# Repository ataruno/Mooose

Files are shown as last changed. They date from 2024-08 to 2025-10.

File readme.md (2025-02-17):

# Mooose

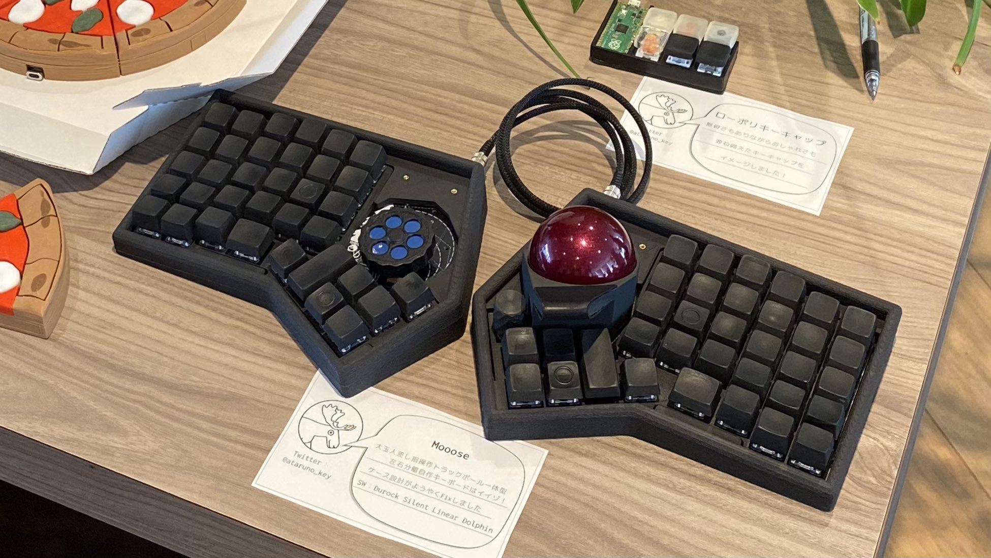
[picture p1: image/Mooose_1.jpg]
Mooose_image


## Features
Keyboard Maintainer: [ataruno](https://github.com/ataruno)  
* Integrated trackball operated with the index finger  
* Supports a 55mm large ball  
* Split design (left and right halves)  
* 70 keys  

## Where to Buy
Booth：[自作キーボード”Mooose”](https://ataruno.booth.pm/items/5795449)

## Build Guide
[ビルドガイドリンク](https://github.com/ataruno/Mooose/blob/main/build_guide/build_guide.md)

ビルドガイドへのQRコード  
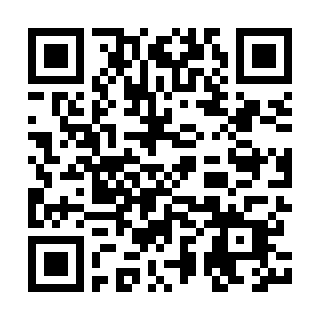
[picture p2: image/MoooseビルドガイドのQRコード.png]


## forCaseDesign
[Moooseのケース設計をしてみたい方へ](https://github.com/ataruno/Mooose/blob/main/forCaseDesign/forCaseDesign.md)  
基板の3Dデータの一部を公開しています。

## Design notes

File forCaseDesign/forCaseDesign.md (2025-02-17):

# Moooseのケース設計をしてみたい方へ
基板の3Dデータの一部を公開します。  

## 3Dデータ(.fbx形式、.stl形式)
[fbx形式 データ置き場リンク](https://github.com/ataruno/Mooose/tree/main/forCaseDesign/forCaseDesign_data/fbx)

[stl形式 データ置き場リンク](https://github.com/ataruno/Mooose/tree/main/forCaseDesign/forCaseDesign_data/stl)

## 簡単な解説
### データのダウンロード
ダウンロードしたいデータファイルまでいき、画像赤枠の"Download raw file"をクリックするとダウンロードできます。  
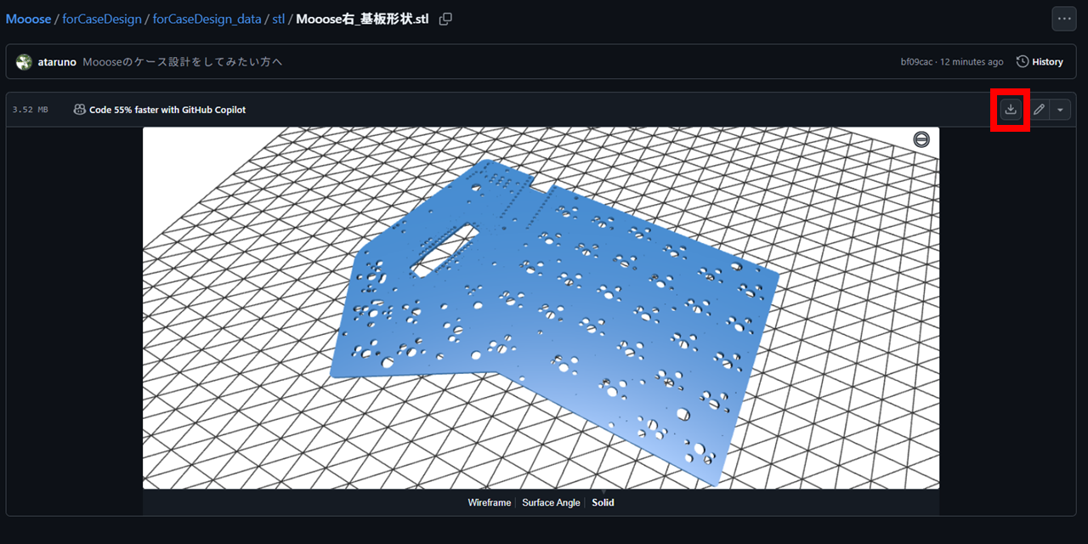
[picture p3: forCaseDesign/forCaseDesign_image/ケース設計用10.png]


### キースイッチの配置
左手側をモチーフに解説します。全体イメージは以下です。  
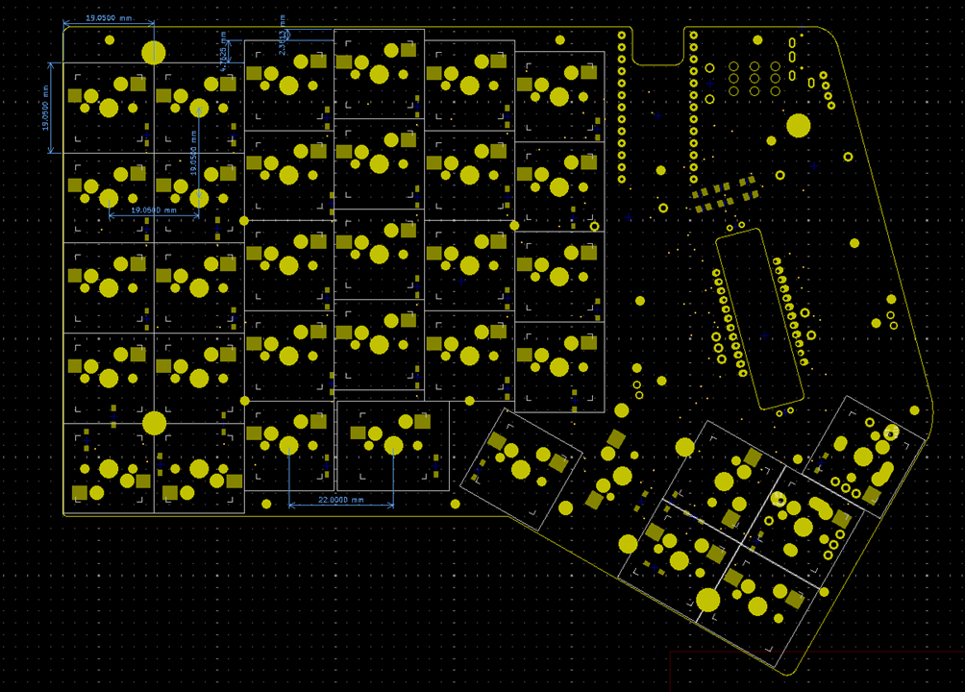
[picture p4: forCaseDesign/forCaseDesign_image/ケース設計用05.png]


キースイッチ一つは19.05mm x 19.05mmで配置しています。  
ずれ量はこの値を基準に1/4ずれ、1/8ずれを使用しています。  
つまり、  
1/4ずれは19.05mm x 1/4 = 4.7625  
1/4ずれは19.05mm x 1/8 = 2.38125  
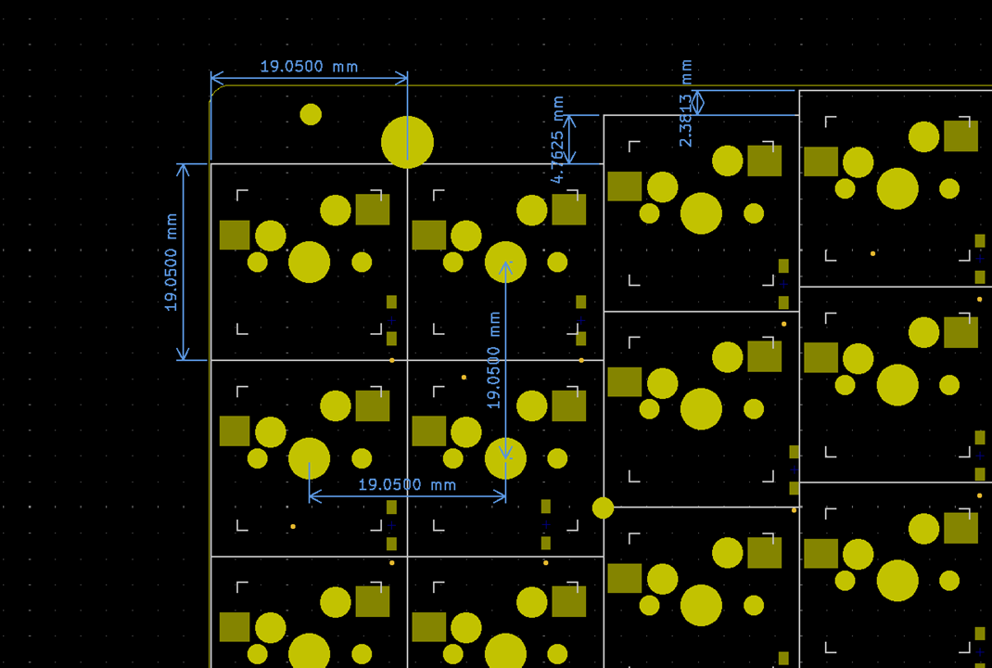
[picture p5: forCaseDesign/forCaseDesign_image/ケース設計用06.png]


真ん中あたりの1.25Uサイズのキースイッチ配置は以下のような感じ。  
隣から22.00mm離れてます。  
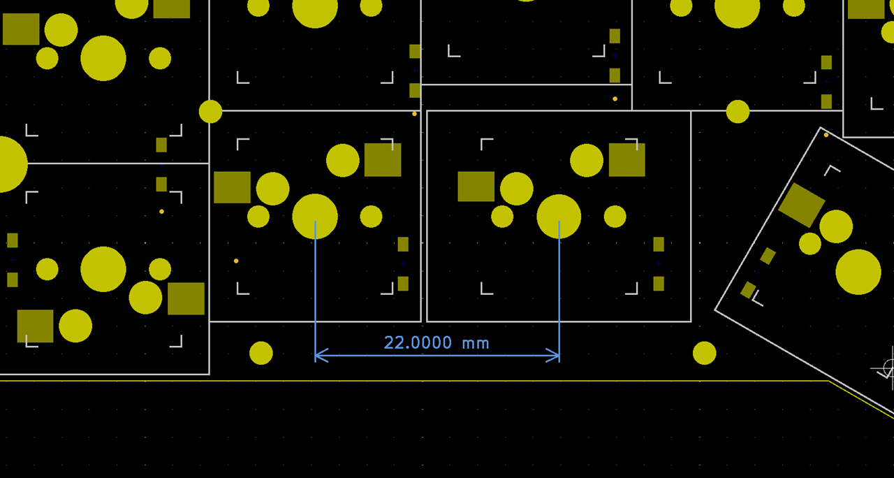
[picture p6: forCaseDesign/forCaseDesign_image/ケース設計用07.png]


### 基板固定用のネジ穴
大きい穴と小さい穴の2種類があります。  
赤丸で囲った穴は直径5.1mm(5mmを通す想定)。黄丸で囲った穴は直径2.1mm(2mmを通す想定)。  
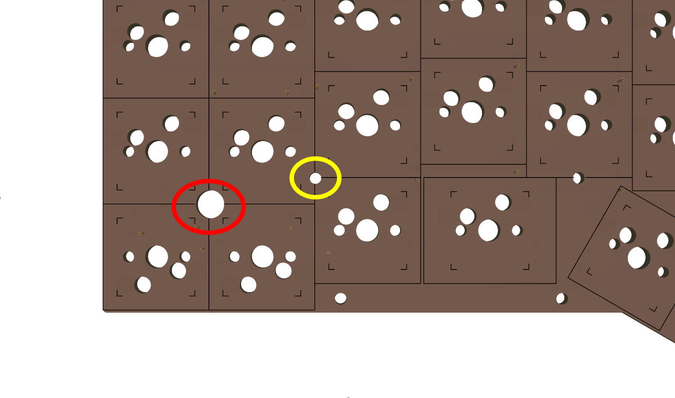
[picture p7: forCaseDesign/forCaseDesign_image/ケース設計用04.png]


### データの取り込み方
使用しているソフトによって異なると思いますが、blenderだと以下です。  
インポートから指定のファイルを選択。  
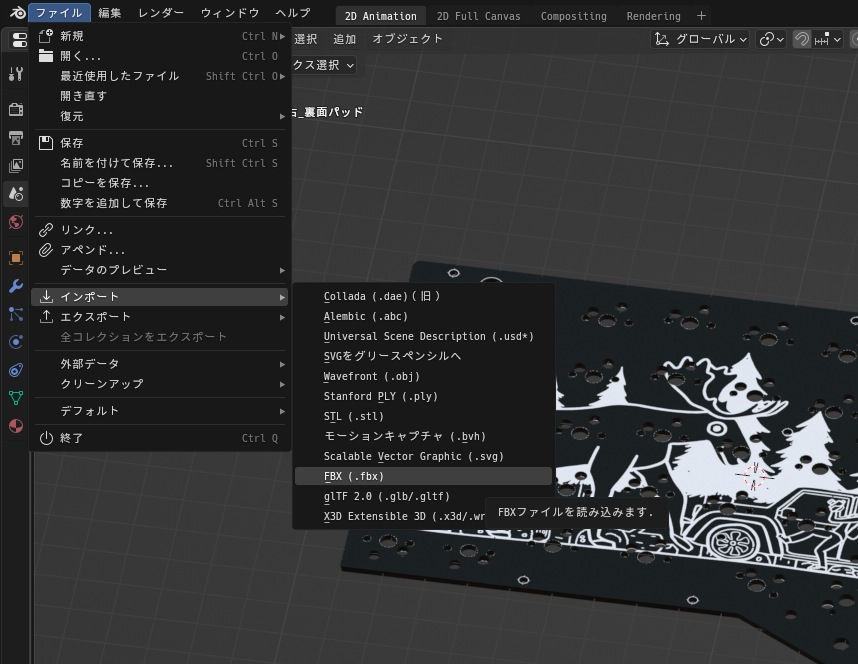
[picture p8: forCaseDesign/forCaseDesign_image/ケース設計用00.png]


fbx形式だとマテリアル(色)がついています。  
また、一つのファイルを読み込むと、4つのデータが取り込まれます。  
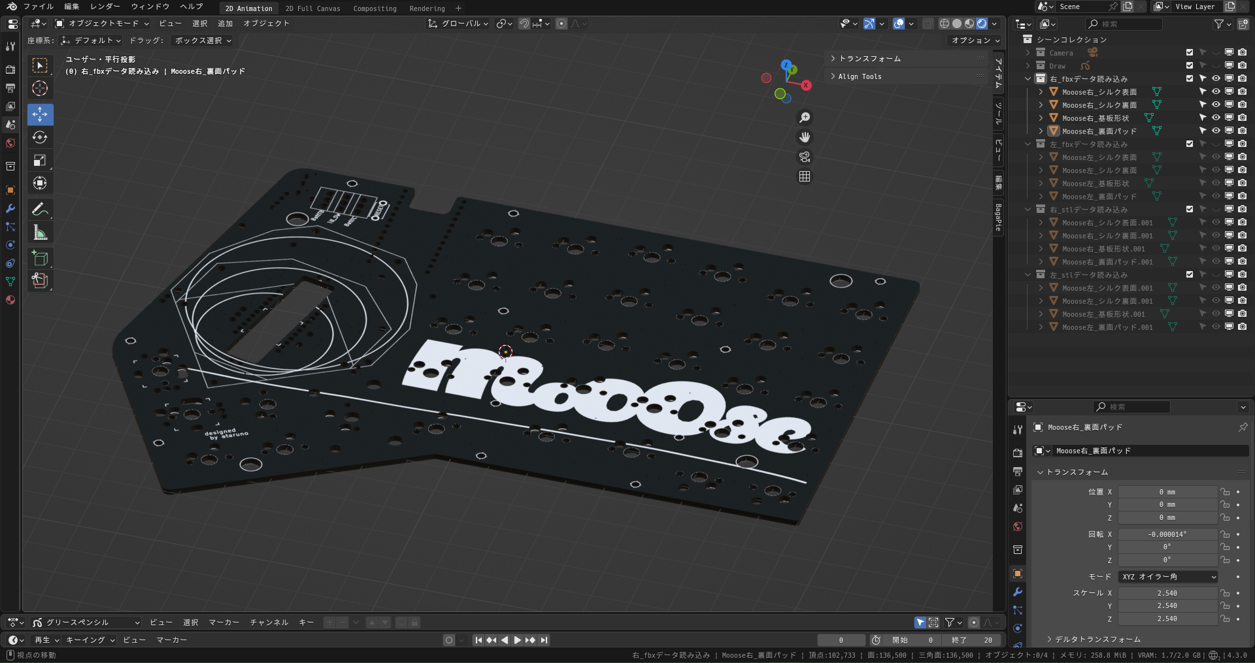
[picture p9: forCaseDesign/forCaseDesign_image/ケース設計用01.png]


stl形式だと色情報がないため真っ白です。  
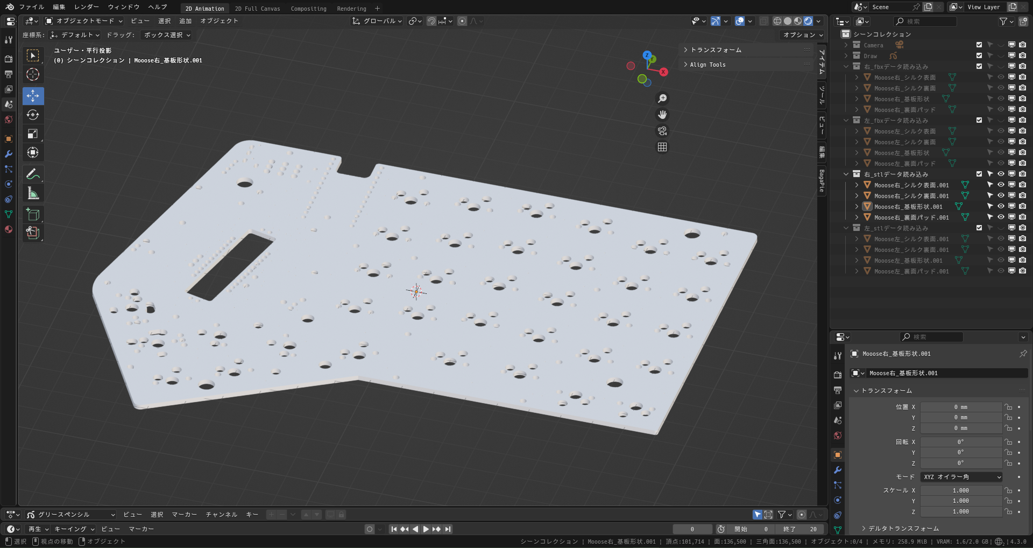
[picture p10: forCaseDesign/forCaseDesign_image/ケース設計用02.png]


ぱっと見見えないけど、位置をずらすと見えたりします。  
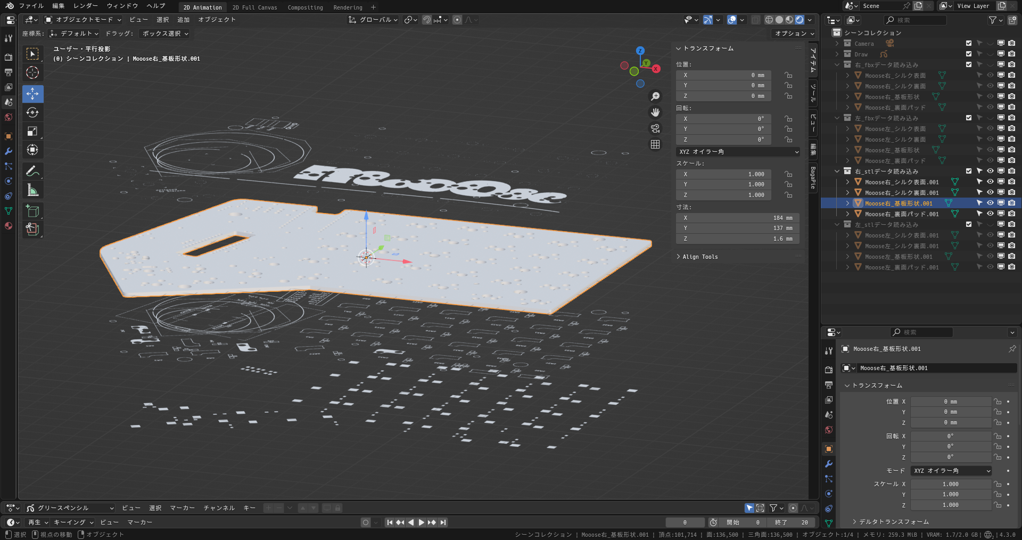
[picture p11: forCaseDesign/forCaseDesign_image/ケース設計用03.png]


## おわりに
ケース設計されたいかたは活用してみてください。
以上です。

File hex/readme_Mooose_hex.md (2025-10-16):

# Moooseのhexファイルごとの解説
2025/08/24現在、トラックボールをつける側とUSB接続する側はそろっている必要があります。  

## mooose_via.hex
* remap対応  
* Master=USB接続:右手  
* トラックボール:右手  

## mooose_via_ML_RightTB.hex
* remap対応  
* Master=USB接続:左手  
* トラックボール:右手  

## mooose_via_Scroll2_MR_RightTB
* remap対応  
* Master=USB接続:右手  
* トラックボール:右手  
* トラボ操作によるスクロール改良版  

## mooose_via_Scroll2_cpi***.hex
* remap対応  
* Master=USB接続:右手  
* トラックボール:右手  
* トラボ操作によるスクロール改良版  
* トラボ感度違いのファイルです。  
  * デフォルトファイルが一番感度が高く、cpiの値が小さくなるほど感度が低くなります。  
  * 不思議なんですが、書き込み終わったら何かキーを打つとcpiが更新されます。

## mooose_via_Scroll2_ML_LeftTB
* remap対応  
* Master=USB接続:左手  
* トラックボール:左手  
* トラボ操作によるスクロール改良版  

## mooose_via_Scroll2_MR_DoubleTB.hex
* remap対応  
* Master=USB接続:右手  
* トラックボール:両方  
  * 右手は通常時マウス操作。レイヤー"LOWER","AHK"状態でスクロール可能。
  * 左手は常時スクロール状態。マウス操作はなし。
* トラボ操作によるスクロール改良版

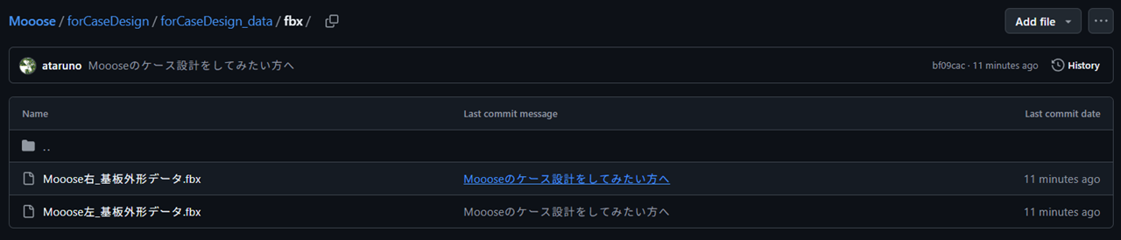
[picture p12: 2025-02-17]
forCaseDesign/forCaseDesign_image/ケース設計用08.png

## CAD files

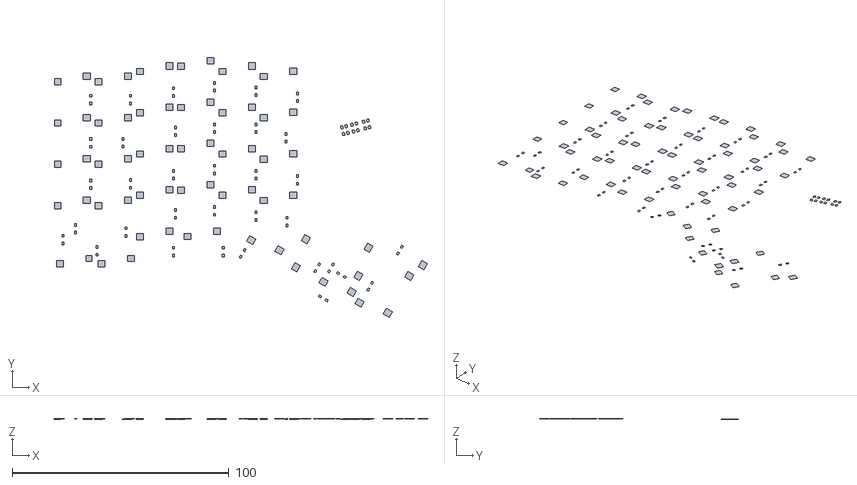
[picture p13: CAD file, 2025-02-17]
forCaseDesign/forCaseDesign_data/stl/Mooose左_裏面パッド.stl
172.0 x 119.8 x 2.86e-05

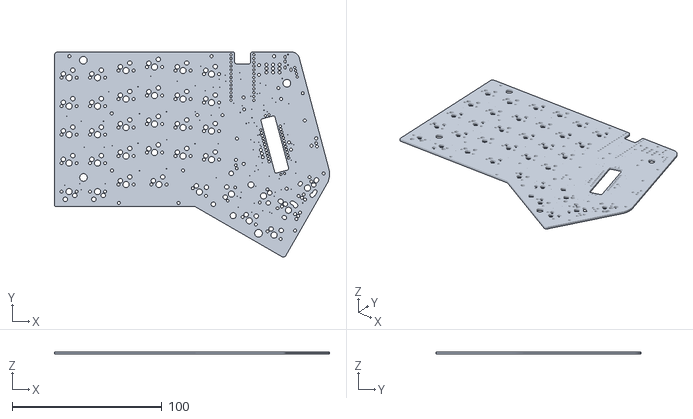
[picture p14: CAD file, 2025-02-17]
forCaseDesign/forCaseDesign_data/stl/Mooose左_基板形状.stl
183.9 x 137.1 x 1.60

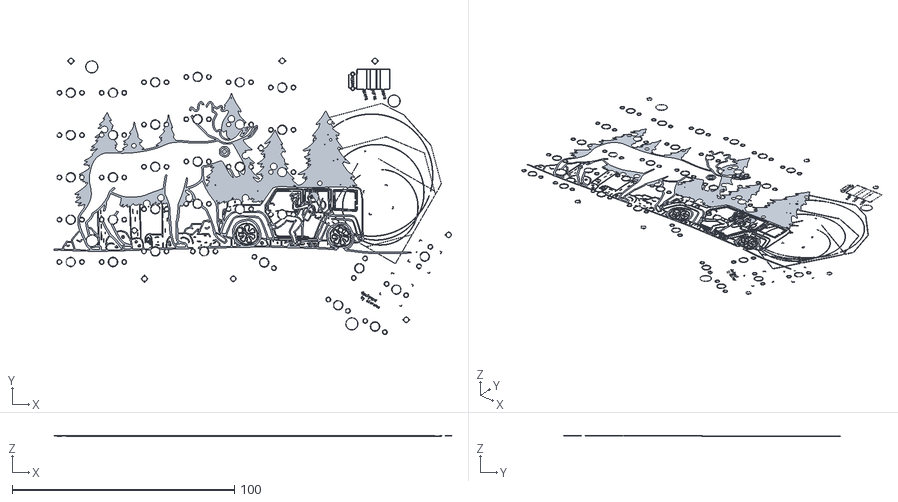
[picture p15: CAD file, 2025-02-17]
forCaseDesign/forCaseDesign_data/stl/Mooose左_シルク表面.stl
179.3 x 124.7 x 2.97e-05

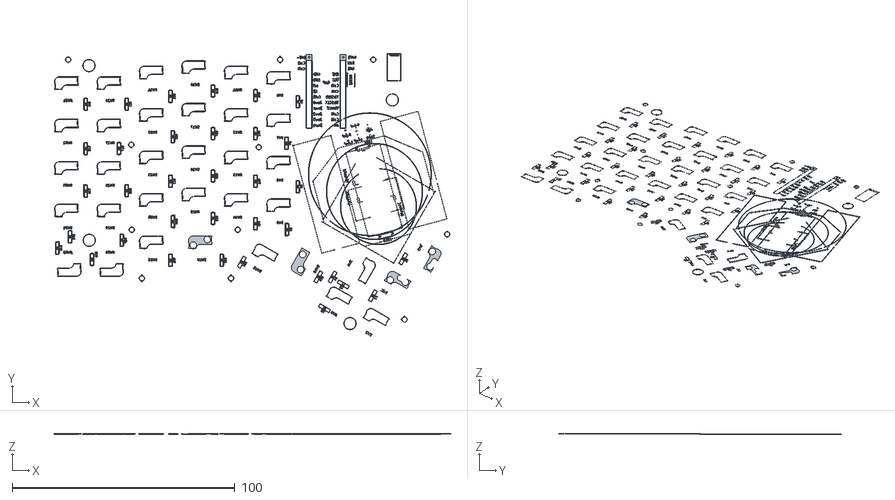
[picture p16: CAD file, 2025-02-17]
forCaseDesign/forCaseDesign_data/stl/Mooose左_シルク裏面.stl
177.7 x 126.9 x 3.03e-05

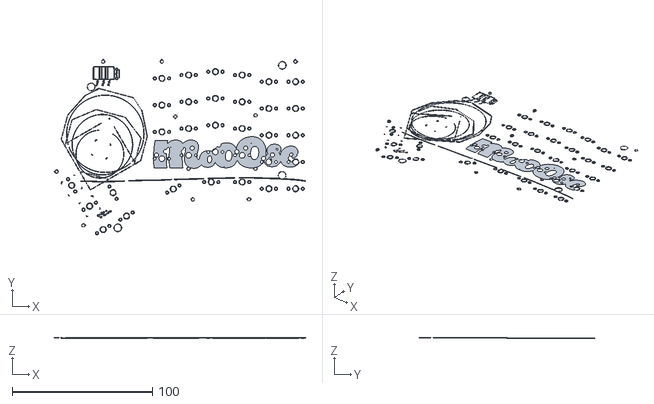
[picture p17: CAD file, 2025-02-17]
forCaseDesign/forCaseDesign_data/stl/Mooose右_シルク表面.stl
178.8 x 124.7 x 2.97e-05

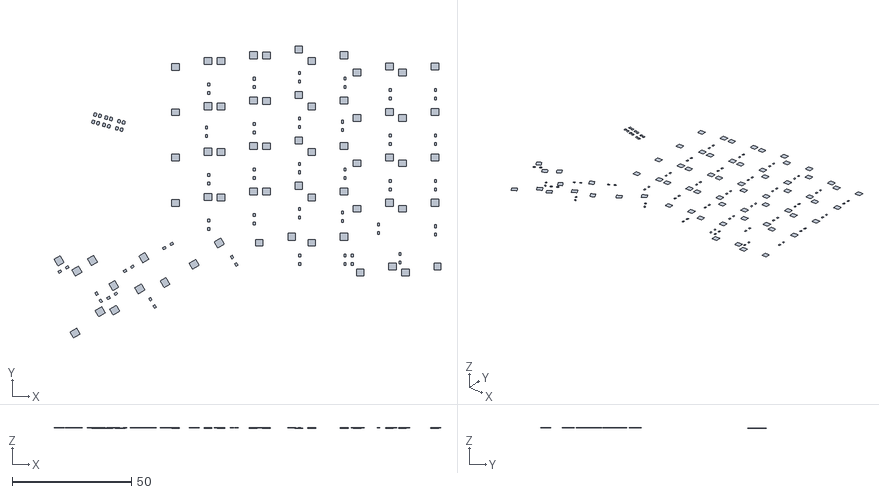
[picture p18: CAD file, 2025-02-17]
forCaseDesign/forCaseDesign_data/stl/Mooose右_裏面パッド.stl
162.4 x 122.5 x 2.93e-05

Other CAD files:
forCaseDesign/forCaseDesign_data/stl/Mooose右_基板形状.stl
forCaseDesign/forCaseDesign_data/stl/Mooose右_シルク裏面.stl

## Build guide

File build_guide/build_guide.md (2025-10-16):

# Moooseのビルドガイド

- [キット内容](#キット内容)
- [ご自身で手配いただくもの](#ご自身で手配いただくもの)
- [はんだ付け](#はんだ付け)
- [組み立て](#組み立て)
- [部品について](#部品について)
- [プログラム書き込み(Remap)](#プログラム書き込みremap)
- [キーマップのカスタマイズ設定](#キーマップのカスタマイズ設定)
- [Userキーについて](#userキーについて)
- [補足:build\_guideの参考情報](#補足build_guideの参考情報)
- [補足:Moooseのケース設計をしてみたい方へ](#補足moooseのケース設計をしてみたい方へ)
- [補足:あれ？動かないな？ってときの確認表](#補足あれ動かないなってときの確認表)
- [おわりに](#おわりに)

## キット内容
以下の内容がキットに含まれます。  
### ケース関係
| ケース関係 | 個数 |
| :--- | --- |
| ケース上部 | 左右1セット |
| ケース下部 | 左右1セット |
| ミドルプレート | 左右1セット |
| エンコーダ部分カバー | 1個 |
| トラボケース下部 | 1個 |
| トラボケース上部 | 1個 |
| ロータリーエンコーダノブ | 1個 |
| トラボケース(レザー) | 1個 |
| ネジ | ＊個 |

追記(25/3/4)：右手側のロータリーエンコーダのノブもキット内容に含めました。  

ある程度組み立てた状態で頒布します。  
ご自身で一度ネジ止めを外してください。  

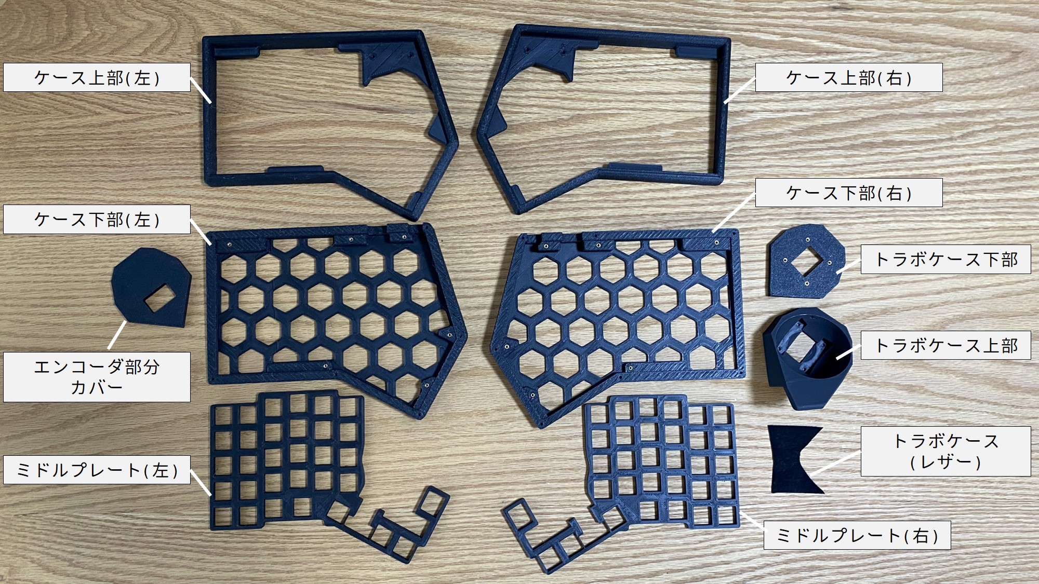
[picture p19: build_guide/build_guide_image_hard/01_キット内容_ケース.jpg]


### 部品関係
| 部品関係 | 個数 |
| :--- | :--- |
| 基板 | 左右1セット |
| 光学センサ | ADNS5050 |
| 発光ダイオード | 1個 |
| 光学センサまわりのもろもろ | もろもろ |
| 55mmトラックボール(赤色) | 1個 |

光学センサまわりははんだ付けして動作確認した状態にします。  
基板設計ミスにつき1部ブリッジしています。  
もし、トラックボールの挙動ががおかしい場合はご連絡ください。  

## ご自身で手配いただくもの
| ご自身で手配いただくもの | 個数 | 例(参考リンク) |
| :--- | :--- | :--- |
| リセットスイッチ(※1) | 左右それぞれ1個 | https://shop.yushakobo.jp/products/a0800ts-01-1 |
| TRRSコネクタ | 2個 | https://shop.yushakobo.jp/products/a0800tr-01-1?_pos=2&_sid=b19f48cbe&_ss=r |
| TRRSケーブル | 1本 | https://shop.yushakobo.jp/products/8023?_pos=3&_sid=b19f48cbe&_ss=r |
| ホットスワップ(MX用) | 70個 | https://shop.yushakobo.jp/products/a01ps?variant=37665172521121 |
| 表面実装ダイオード(1N4148W) | 70個 | https://shop.yushakobo.jp/products/a0800di-02-100?variant=37665574420641 |
| キースイッチ(MX互換) | 70個 | ※ロープロファイルは未対応です。 |
| promicro(※2) | 左右それぞれ1個 | ・https://shop.yushakobo.jp/products/21<br>or<br>・https://shop.yushakobo.jp/products/pro-micro |
| ロータリーエンコーダ<br>(軸形状:Dカット、高さ20mm or 22.5mm)  | 任意 | https://shop.yushakobo.jp/products/3762?variant=42672275292391 |

※1:タクタイルスイッチ - 2pin 3.5x6x4.3mm  
※2:
Type-Cは少し基板が大きいとのこと。基板をねじ止め固定仕様とすると干渉するためType-Bをお選びください。耐震シートを引く場合は収まります。  
追記(25/3/4)：3/4以降、ケースを改良しType-C版でも干渉しないにしました。  
※トラックボールあり/なしのバリエーション販売しています。  
  なしを選択した方はご自身でご準備ください。  
  **黒玉だと反応が悪いため、赤玉をご準備ください。**  
  (ただ、当面はボールありを優先して用意します。ボール無しで欲しい方Boothなどでメッセージいただけましたら用意します。)  
※ロータリーエンコーダ背が低い17.5mmだと押込みクリックが効かない場合があります。

## はんだ付け
### 裏面(はんだ付け前→はんだ付け後)
左側がはんだ付け前の素の基板、右側がはんだ付け後の基板です。  
(光学センサのはんだ付け、おおちゃくしています。)  
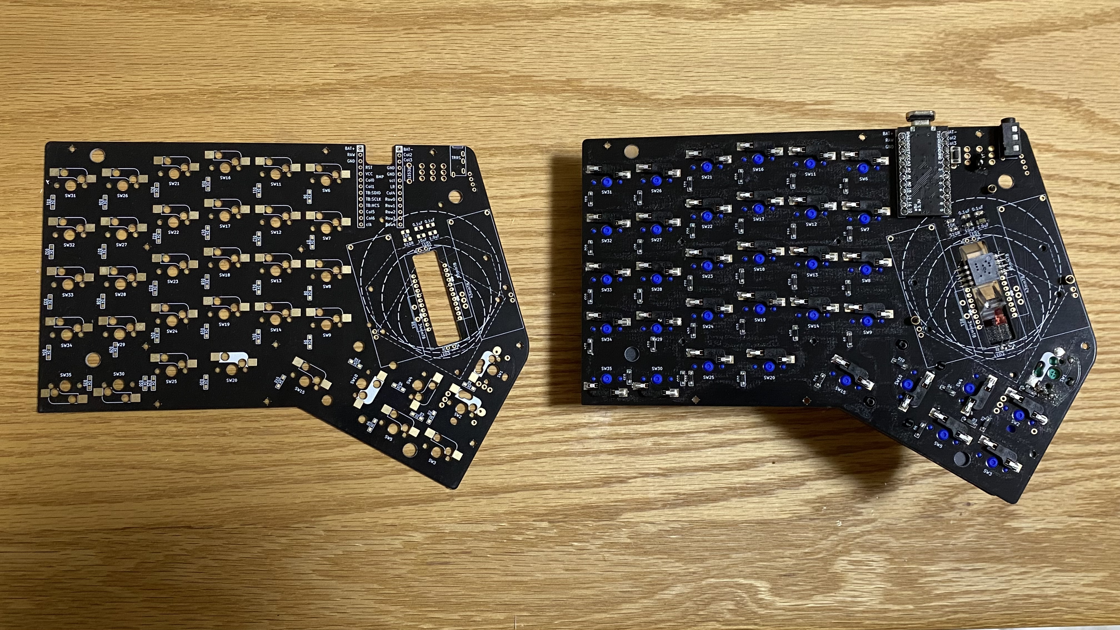
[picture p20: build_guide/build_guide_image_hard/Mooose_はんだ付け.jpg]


### 基板データ画像とPDF
はんだ付け部分がわかりやすいよう基板データの画像とPDFファイルも置いておきます。  

#### 右手  
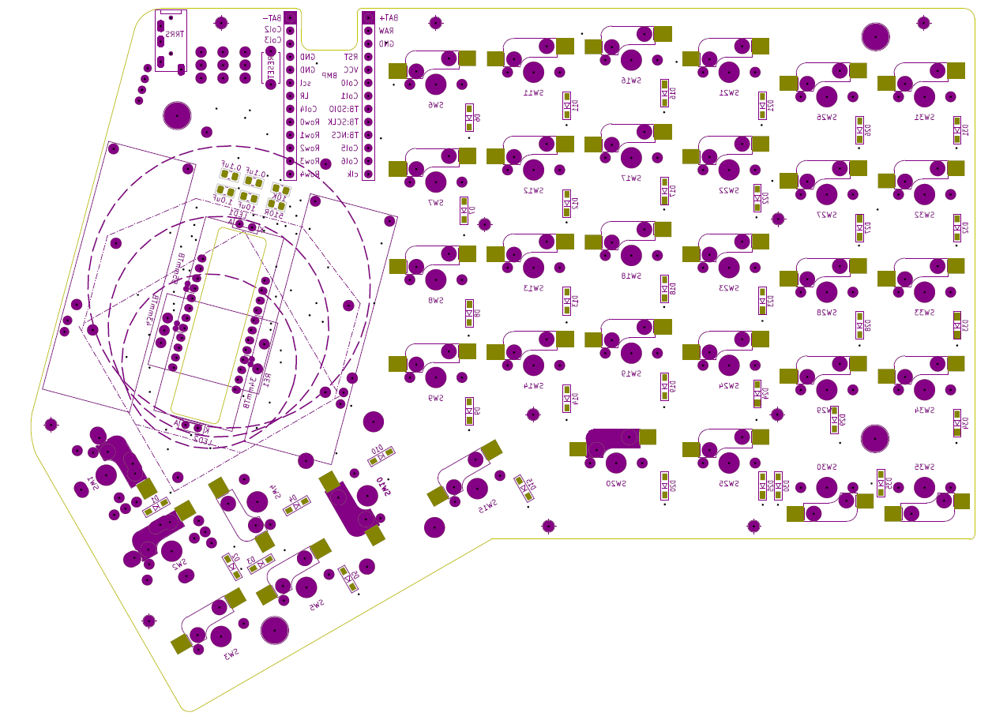
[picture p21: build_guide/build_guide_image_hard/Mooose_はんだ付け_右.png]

[PDFファイルリンク](https://github.com/ataruno/Mooose/blob/main/build_guide/build_guide_image_hard/%E3%81%AF%E3%82%93%E3%81%A0%E4%BB%98%E3%81%91%E3%82%8F%E3%81%8B%E3%82%8A%E3%82%84%E3%8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)

#### 左手  
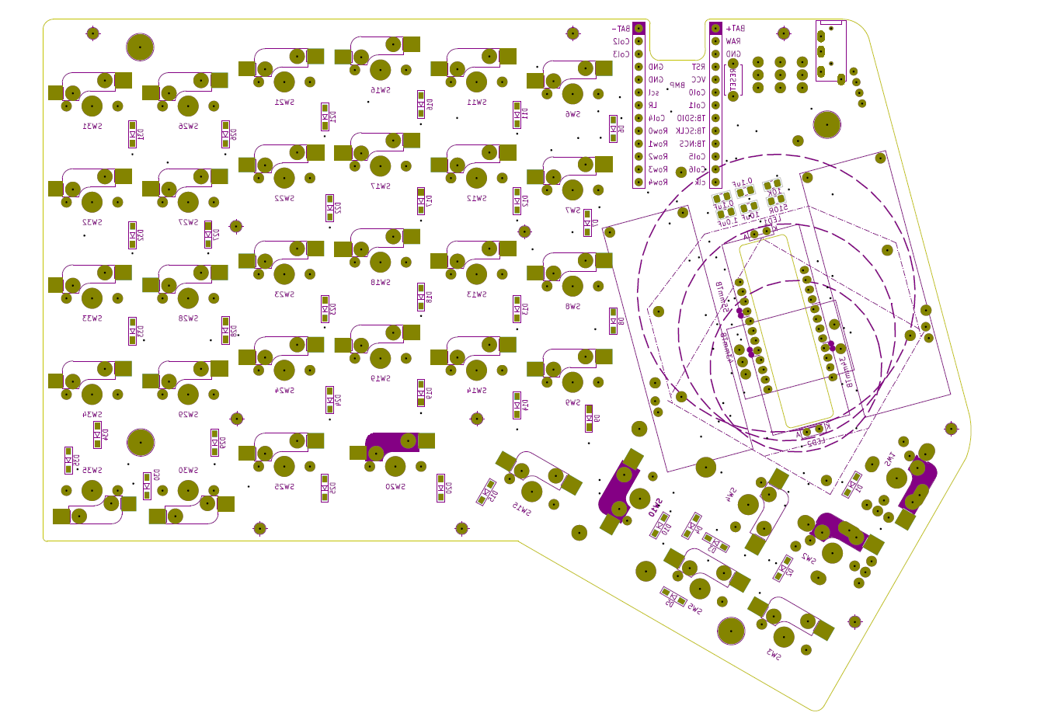
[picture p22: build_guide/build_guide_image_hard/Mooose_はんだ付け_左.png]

[PDFファイルリンク](https://github.com/ataruno/Mooose/blob/main/build_guide/build_guide_image_hard/%E3%81%AF%E3%82%93%E3%81%A0%E4%BB%98%E3%81%91%E3%82%8F%E3%81%8B%E3%82%8A%E3%82%84%E3%8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)

### 表面実装ダイオード
Dと書いてある部分にダイオードのはんだ付けが必要です。  
画像中央やや右のD2部分を見るとわかるように■▷｜■とあります。  
この棒線がある方向(画像だと右側)に、ダイオードの縦線を合わせてください。  
画像中央やや左のD1も画像右側にダイオードの縦線が向いています。  
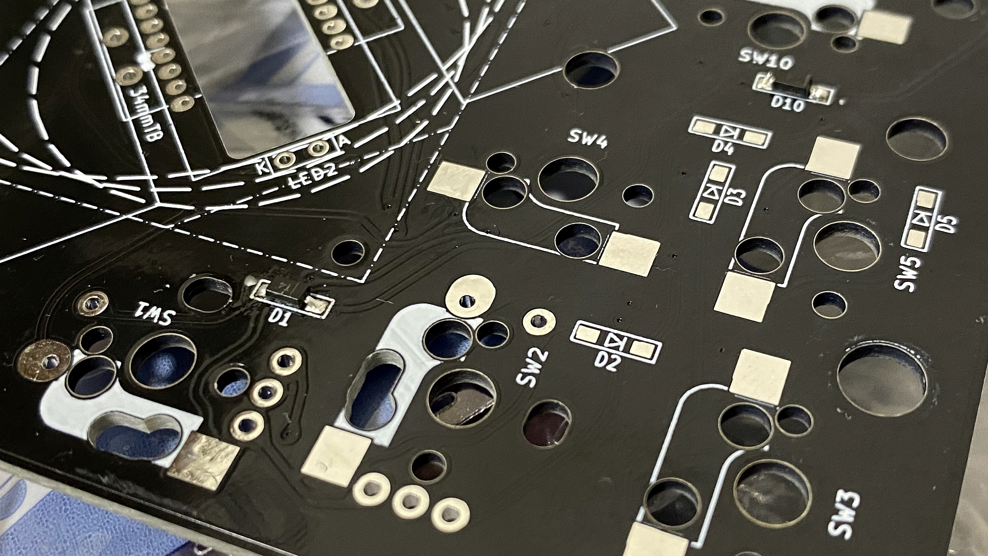
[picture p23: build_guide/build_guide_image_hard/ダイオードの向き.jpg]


### スイッチソケット
スイッチソケットも以下のようにはんだ付けしてください。  
画像は右手基板の裏側です。  
テープモッドしてたのを外したので、粘着剤がついてますが気にしないでください…。  
合わせてプロマイクロも以下のようにはめてください。  
もちろんピンヘッダーでも接続可能ですが、何かあったときに面倒なのでコンスルー推奨です。  
右上(プロマイクロ部分)  
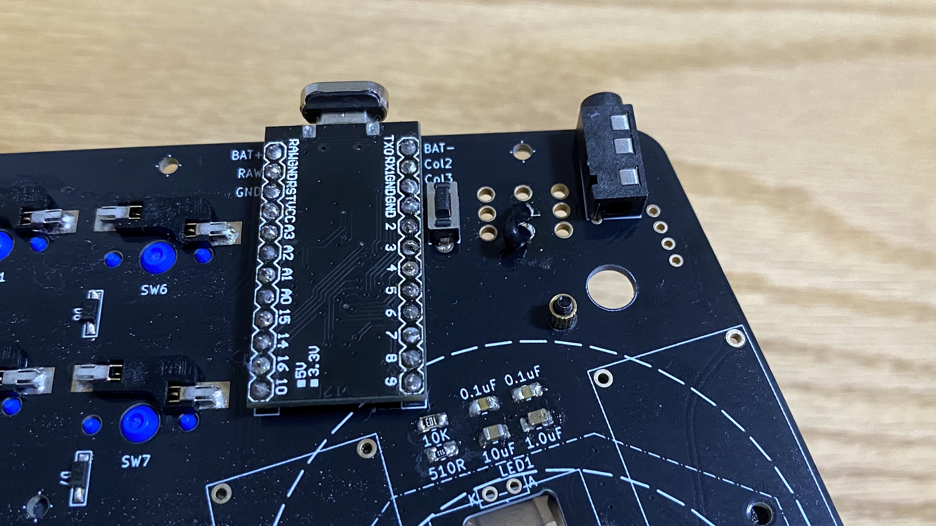
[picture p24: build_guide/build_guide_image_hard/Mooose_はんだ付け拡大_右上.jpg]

右下  
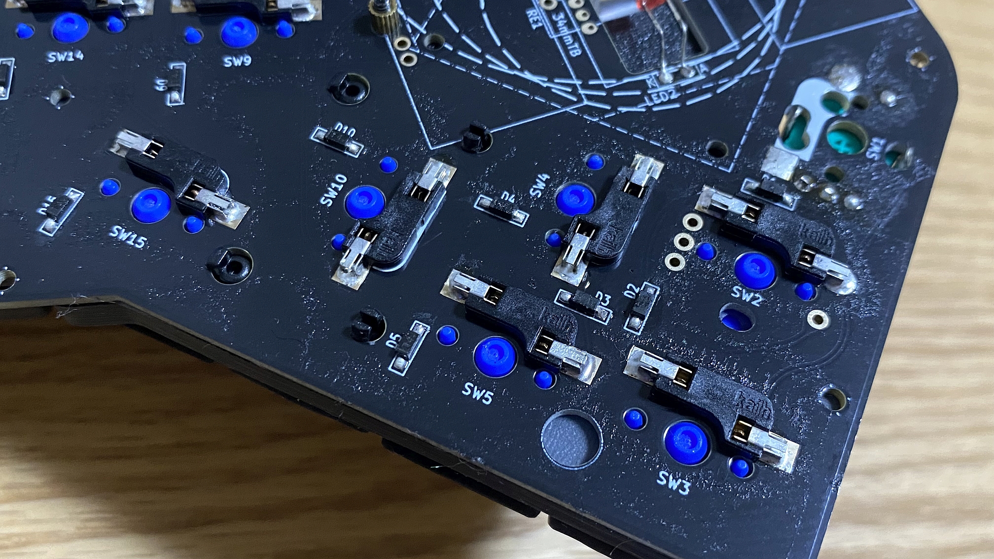
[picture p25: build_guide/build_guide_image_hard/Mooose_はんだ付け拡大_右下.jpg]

左上  
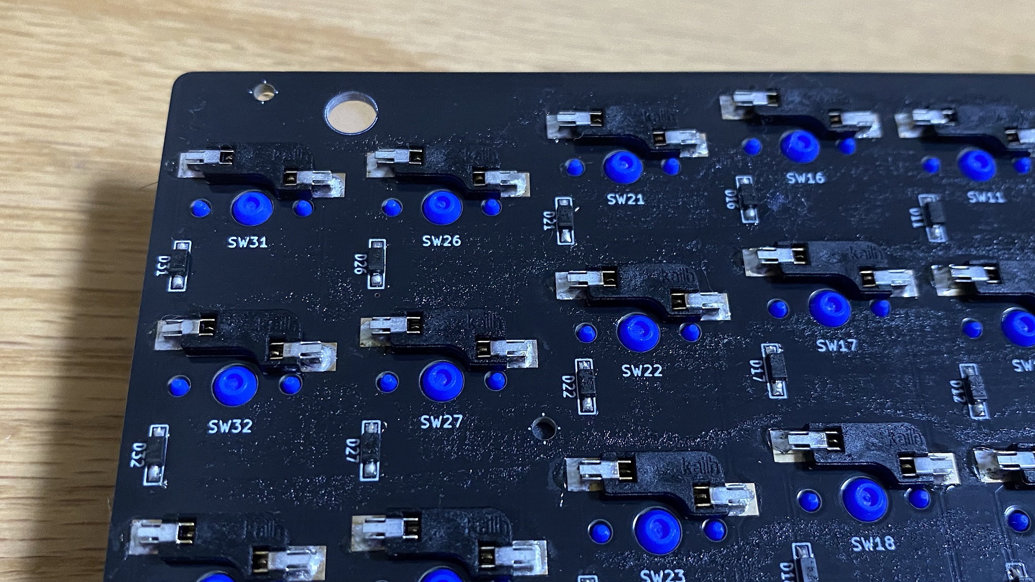
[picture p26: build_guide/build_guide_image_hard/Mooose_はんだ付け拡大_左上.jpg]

左下  
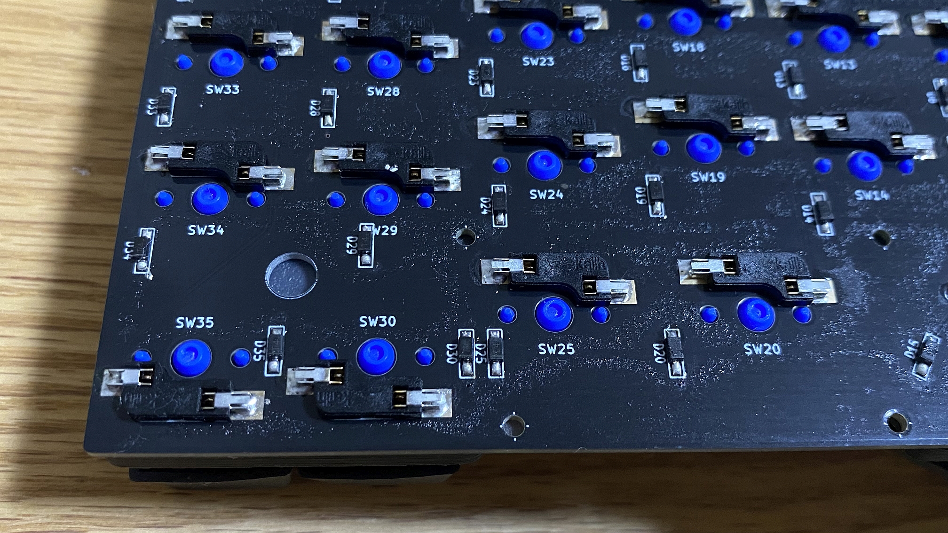
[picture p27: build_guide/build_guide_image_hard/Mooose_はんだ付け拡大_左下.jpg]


### 光学センサ付近
光学センサまわりの部品ははんだ付けし、動作確認した上で発送しています。  
光学センサ付近は、LEDがやや浮くような配置になります。  
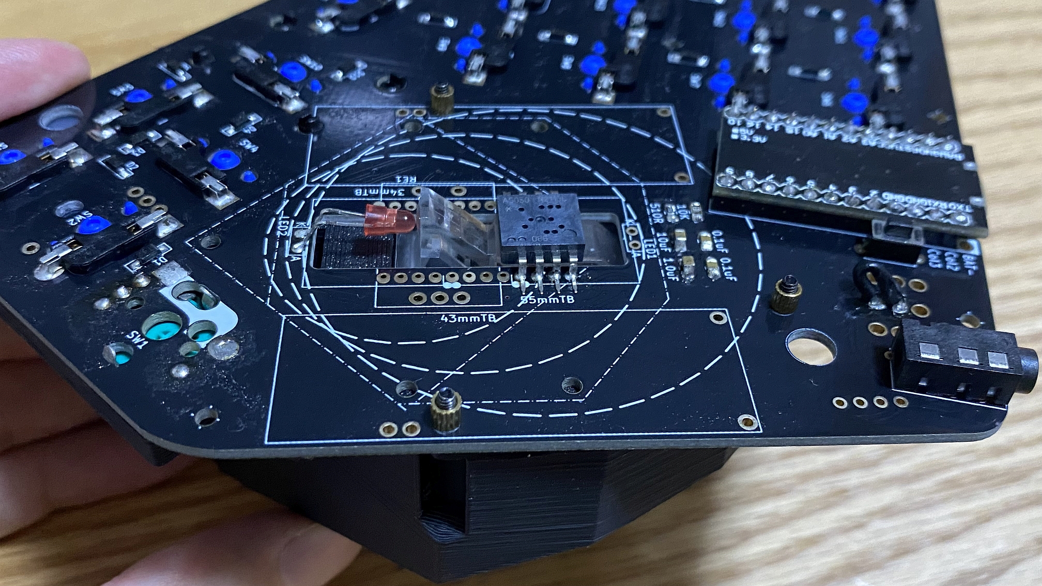
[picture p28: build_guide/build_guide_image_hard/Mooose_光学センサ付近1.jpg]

LEDがセンサレンズの真ん中に来るようにしてください。  
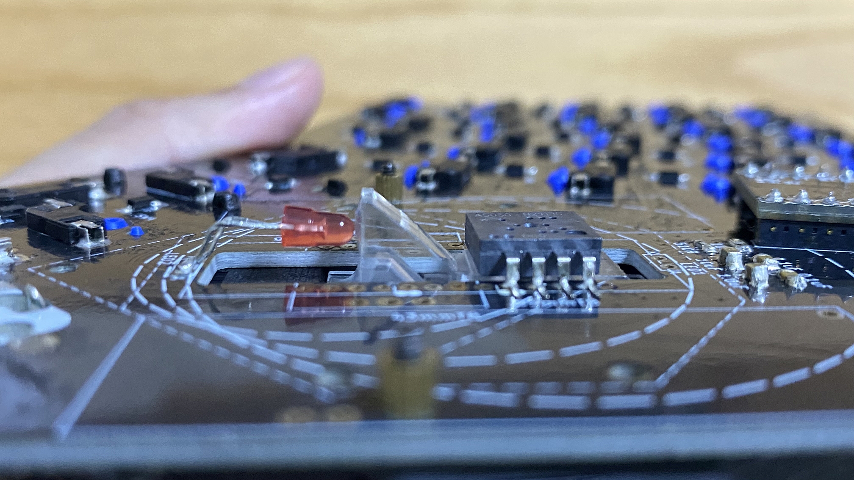
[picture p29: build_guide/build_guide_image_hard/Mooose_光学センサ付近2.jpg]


```
『開発小話』
Mooose、実は光学センサの位置が3か所選べます。
ただ、対応したケースをそれぞれ頒布キットの中に含むのは途方もないので、大玉が使える位置をベースにしています。
興味ある人は光学センサの位置変えた上で、トラボケースを自設計＆自宅の3Dプリンタ印刷したりカスタマイズしてみてください。
```

### ロータリーエンコーダ付近
親指ロータリーエンコーダ付近ですが、以下のようにはんだ付けできます。  
ロータリーエンコーダでなくスイッチでも可能です。  
下の画像は右手基板の裏側です。  
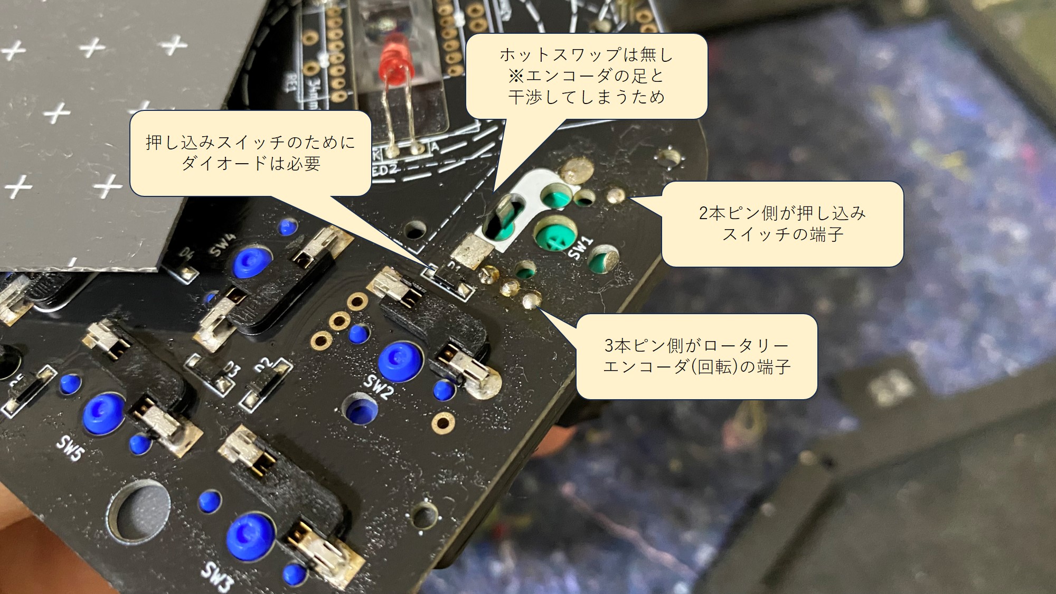
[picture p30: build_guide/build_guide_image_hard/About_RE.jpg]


光学センサと同じ位置のロータリーエンコーダ(写真は左手側基板)の取付もむちゃしています。  
足を広げてはんだ付けしてください。ギリギリ届くはずです。  
下の画像は左手基板の表側です。  
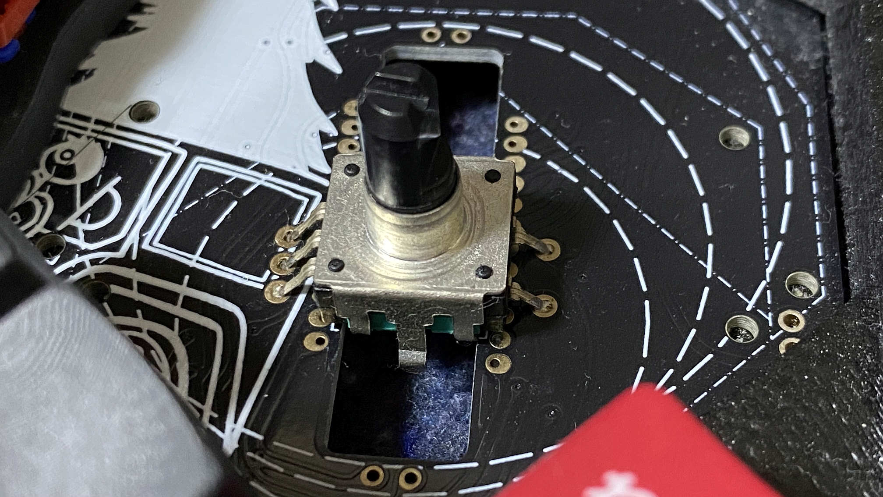
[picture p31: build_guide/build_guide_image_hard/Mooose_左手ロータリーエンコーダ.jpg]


```
『開発小話』  
基板上にはロータリーエンコーダを取り付ける場所が複数個存在しています。  
これらは電気的にすべてつながっています。  
この設計意図は好きな位置に取り付けられるようにするためです。  
そのため、片側基板内で位置違いで複数の機能を持たせることはできないです。  
右手と左手で別の機能にすることはQMK上で可能です。  
レイヤーキーを駆使して複数機能割り当てはもちろん可能です。  
```

追記：上記の小話をさらに図を使って説明します。  
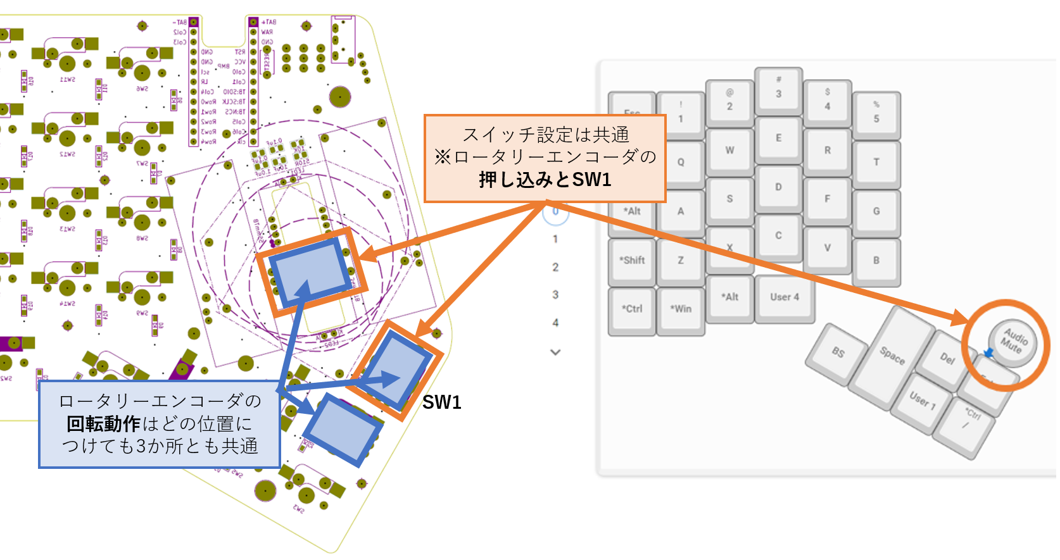
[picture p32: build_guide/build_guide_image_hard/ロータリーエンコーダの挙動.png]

ということです。上記の図は左手側ですが、右手側も同じハード構成です。  

## 組み立て
### トラックボール筐体
トラックボール筐体の取付は以下です。  
右手側、裏からねじ止めしています。２か所固定できれば十分かと思います。  
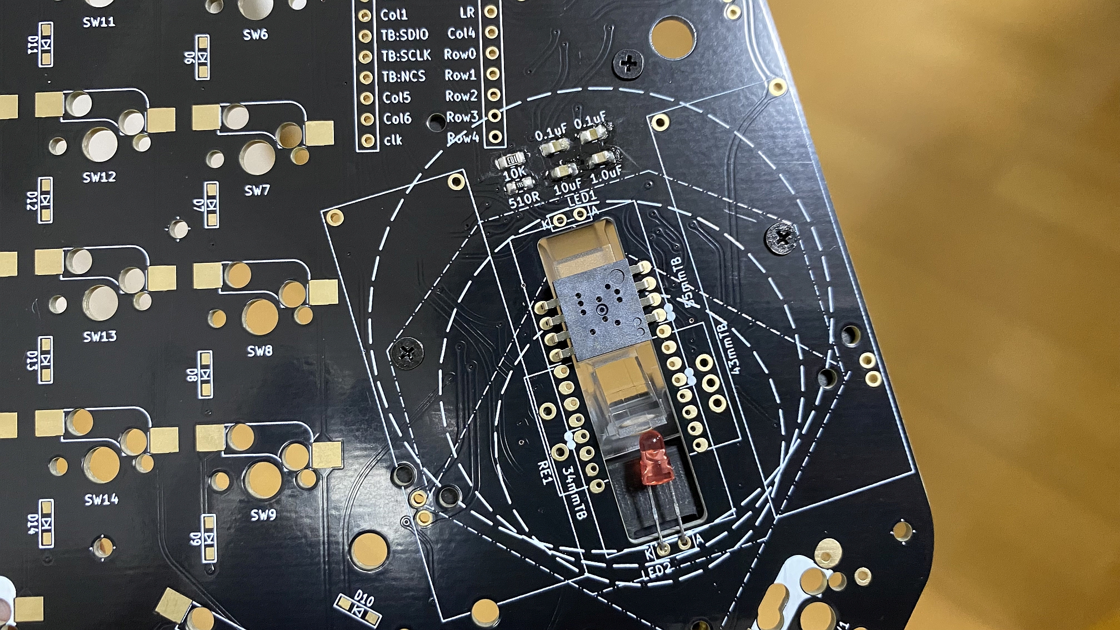
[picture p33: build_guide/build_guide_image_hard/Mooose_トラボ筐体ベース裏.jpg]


表側はこのような感じ。  
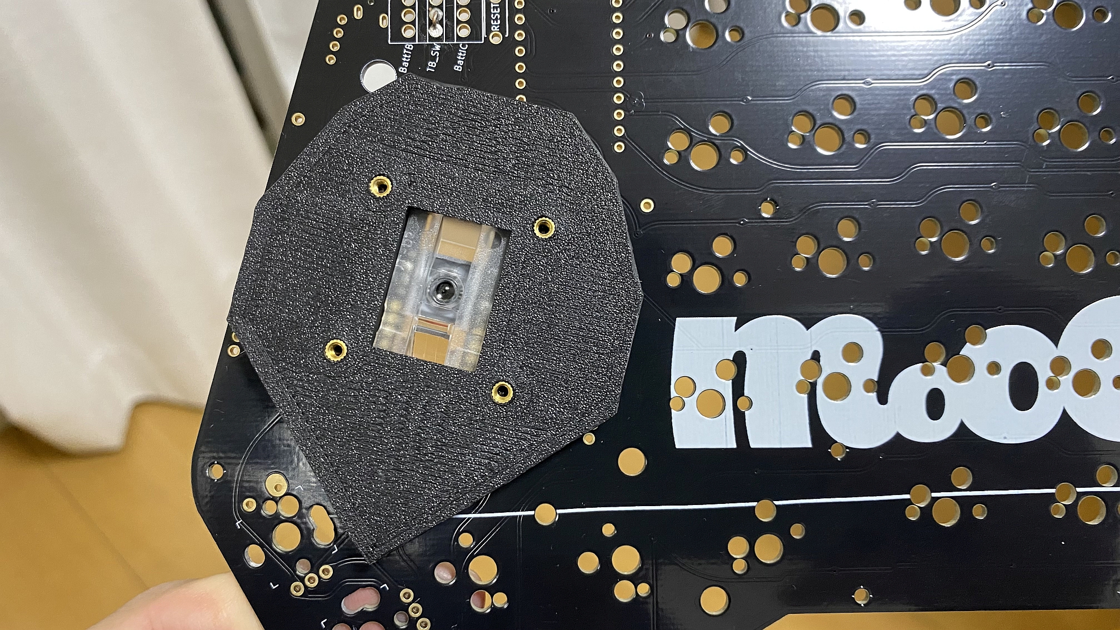
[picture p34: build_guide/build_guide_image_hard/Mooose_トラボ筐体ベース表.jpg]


トラックボールが乗る筐体部分はさらにこの上からねじ止めします。  
こちらも穴が4か所ありますが、2か所止めれば十分止まると思います。  
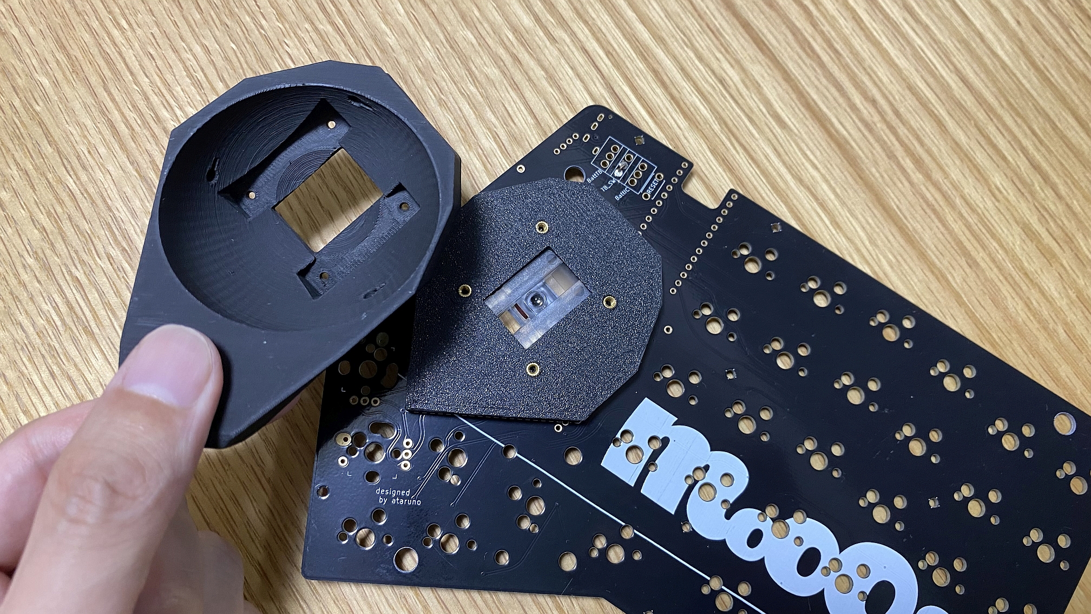
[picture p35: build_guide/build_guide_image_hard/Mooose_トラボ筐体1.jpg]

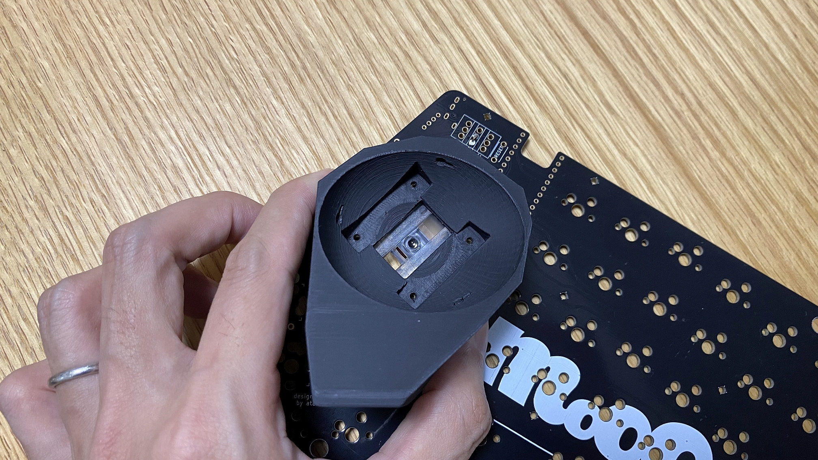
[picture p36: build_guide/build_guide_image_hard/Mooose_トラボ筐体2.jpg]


#### レザーカバー
レザーのカバーを同封しています。お好みで接着してご使用ください。  
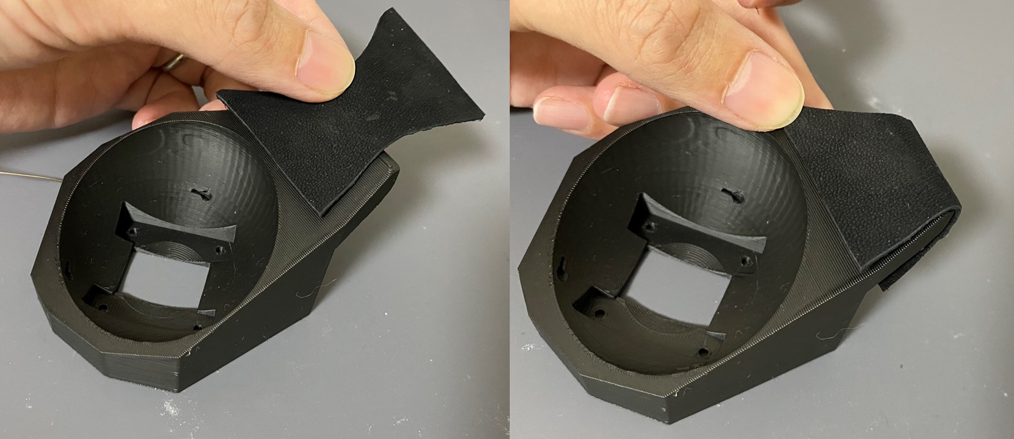
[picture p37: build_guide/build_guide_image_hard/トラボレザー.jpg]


あくまで一つの参考ですが、レザーとプラスチックの接着剤などが良いかと思います。  

### ケース
ボトムケースにはんだ付けした基板をはめます。  
マウント方法はネジ止めと耐震シートを引く方法の2種類があります。  
ねじ止めするときは単純にネジでとめてください。
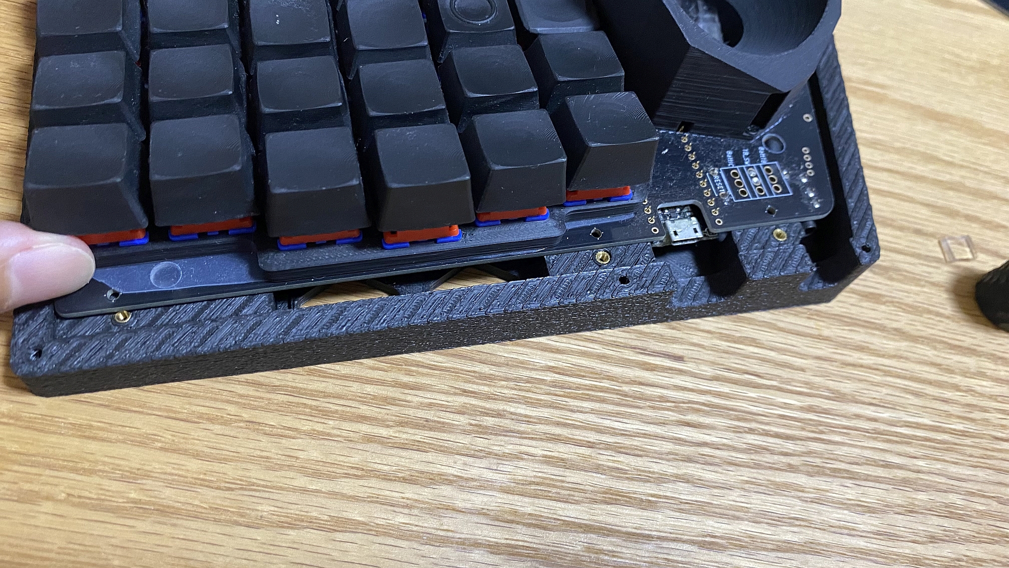
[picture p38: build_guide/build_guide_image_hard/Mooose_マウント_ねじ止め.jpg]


耐震シートを引く方法は以下。  
耐震シートをサイズに合わせてハサミで切って貼ります。  
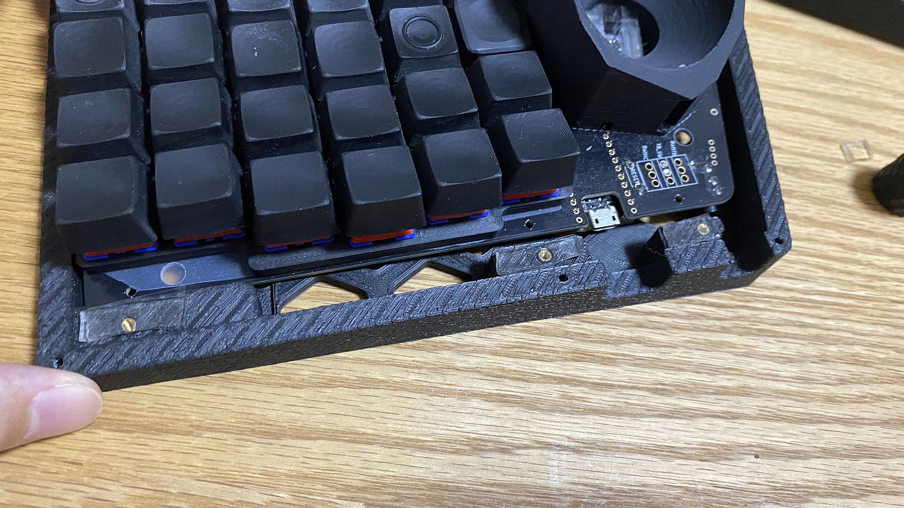
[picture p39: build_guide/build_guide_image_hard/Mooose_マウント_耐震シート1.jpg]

んで、載せます。
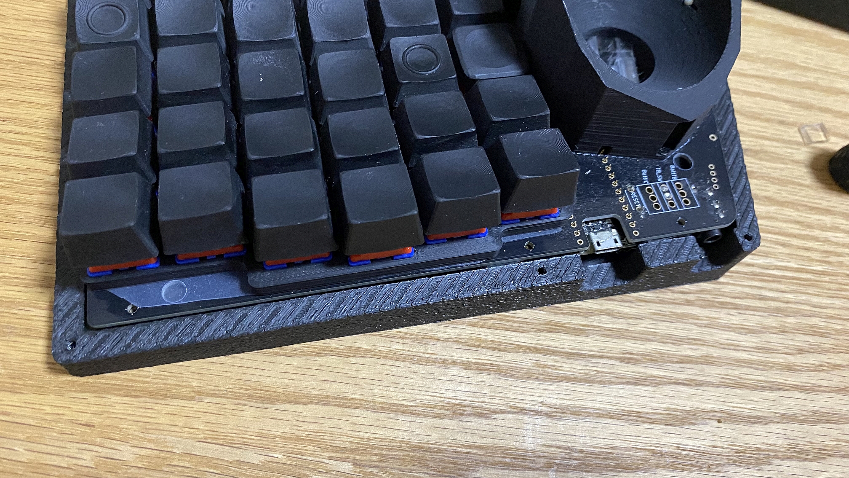
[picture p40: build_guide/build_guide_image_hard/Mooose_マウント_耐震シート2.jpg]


ちなみに耐震シートは100円均一とかで変えるこういうやつ。  
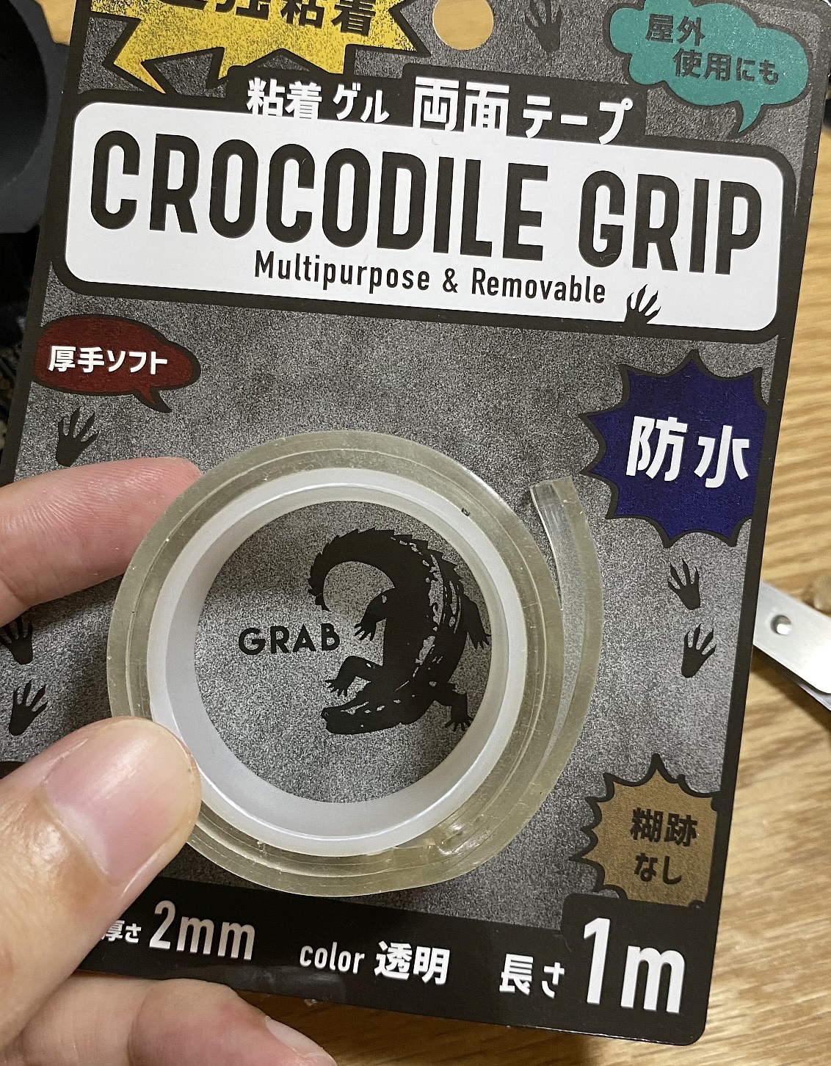
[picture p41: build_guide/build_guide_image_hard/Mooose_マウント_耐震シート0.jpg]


ねじ止めでも耐震シート貼る方法でもマウント箇所は６か所。  
さらに上から筐体を被せて7か所背面からねじ止めします(ボトムケースとトップケース)。  
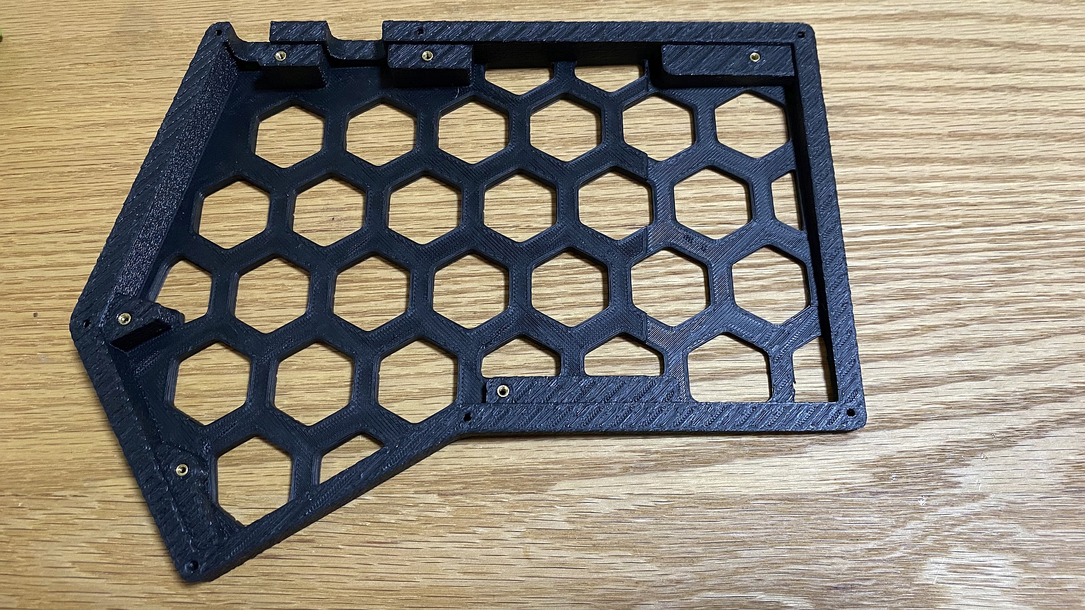
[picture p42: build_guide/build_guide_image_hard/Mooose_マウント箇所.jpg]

横から見るとこんな感じになります。TRRSケーブルやUSBの部分に穴が開いています。  
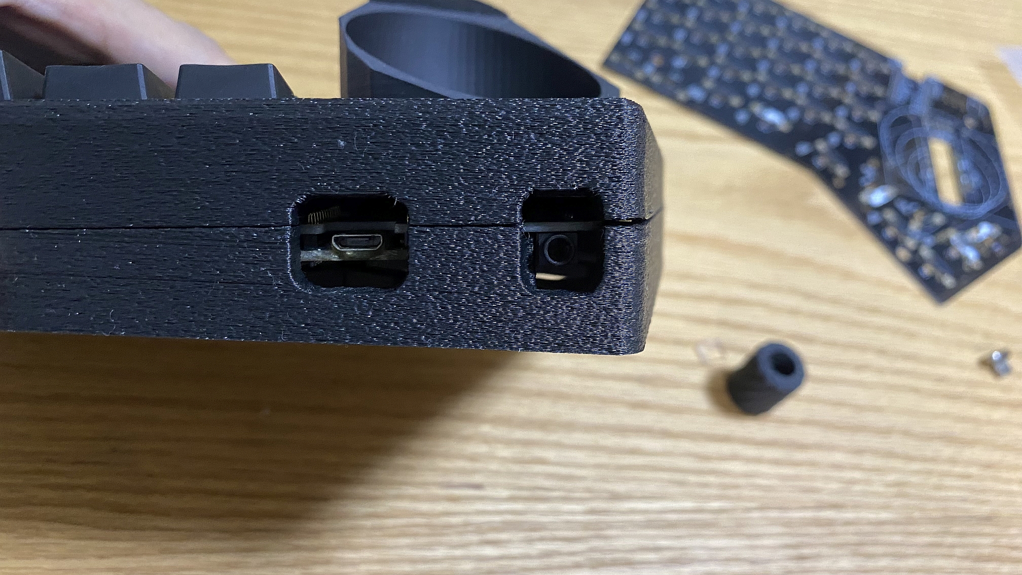
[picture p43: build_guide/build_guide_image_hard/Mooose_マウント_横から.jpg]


### ロータリーエンコーダノブ
ロータリーエンコーダは軸の形状がD型を想定しています。  
購入するときはご注意を。  
左手側は2パーツに分かれています。  
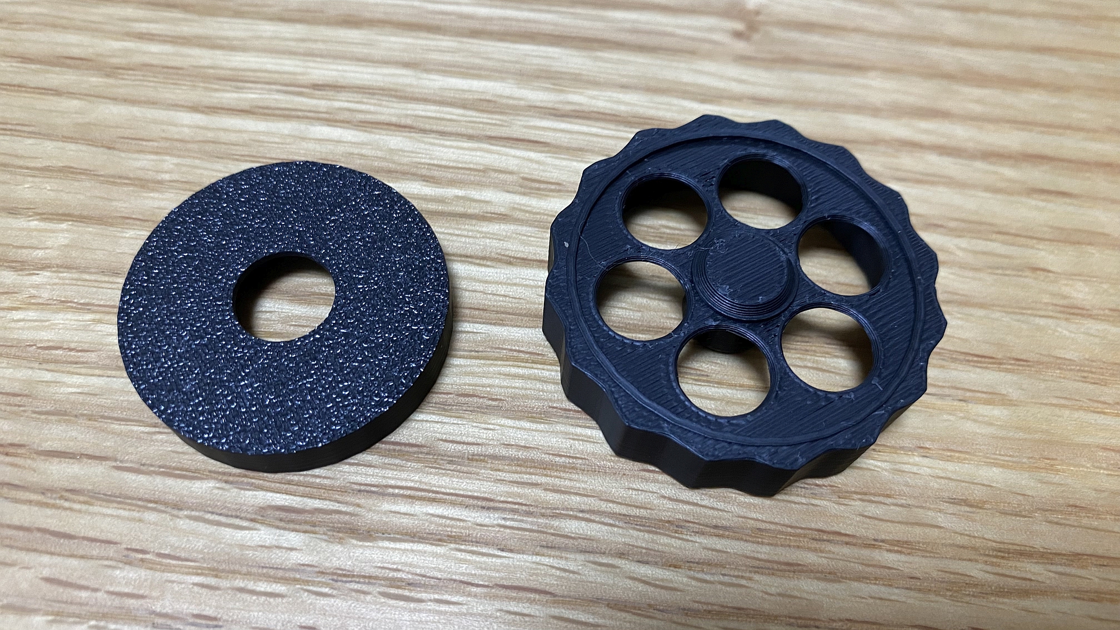
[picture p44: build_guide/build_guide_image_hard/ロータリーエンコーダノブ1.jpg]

重ねてこの辺りを接着剤などで止めてください。  
このとき外側パーツと内側パーツの間にすきなものを挟むと、表から見たときにチラ見えします。  
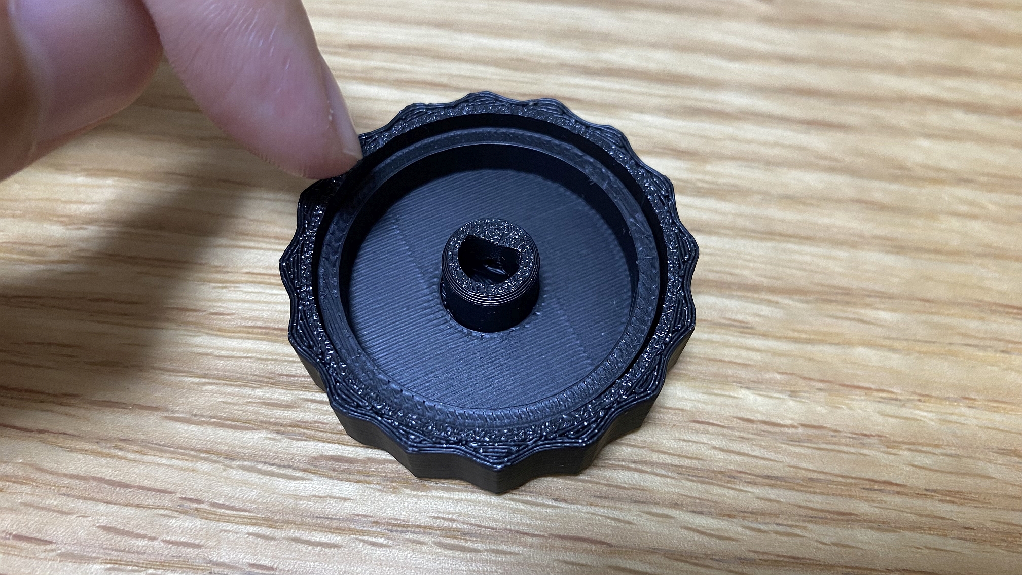
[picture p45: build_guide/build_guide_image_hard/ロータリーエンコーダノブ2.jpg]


何も挟まなくとも印刷面の違いがあって良い感じです。  
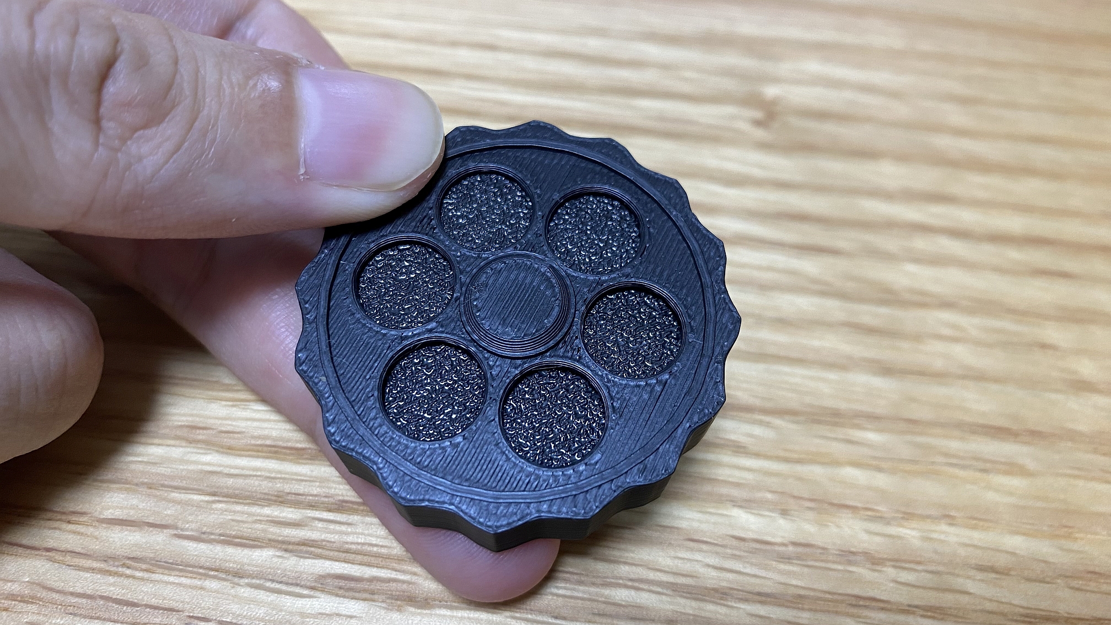
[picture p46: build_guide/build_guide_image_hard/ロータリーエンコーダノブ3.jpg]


右手側ははめ込むのみです。  
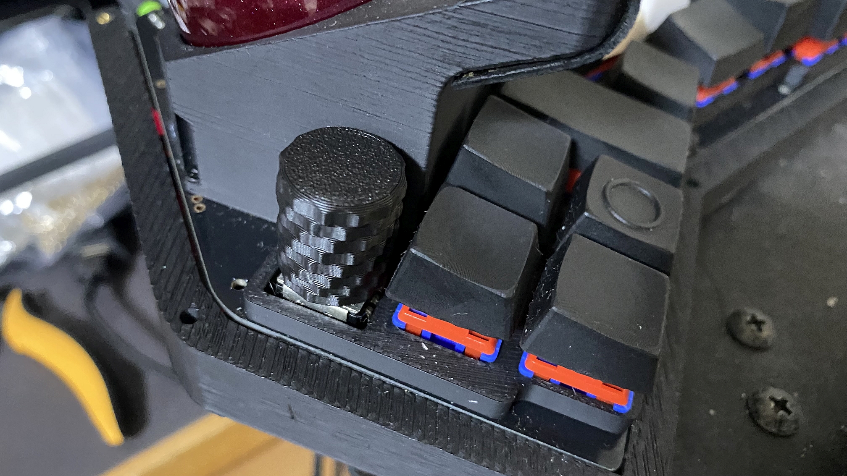
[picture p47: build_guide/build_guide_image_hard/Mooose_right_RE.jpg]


### 組み立ての完成
おおよそ以下の形になります。  


## 部品について
家庭用の3Dプリンターで製造しているため、製造にばらつきがあります。ご了承ください。  
事前に組み立てを行い、問題ないと判断したものをキットとしています。  
ご理解のほどよろしくお願いいたします  

## プログラム書き込み(Remap)
### Remapへアクセス
Remapの[Moooseのファームウェアページ](https://remap-keys.app/catalog/MlyqSV68nIYDRLw4srxW/firmware)へアクセスします。
(ブラウザはChromeとEdgeで書き込みできることを確認済です。)  

### 書き込み
あらかじめ、キーボードとPCをUSBケーブルで接続してください。  

書き込みたい対象のファームウェアの"書き込み"をクリックします。  
※ファームウェアは**左右のマイコンそれぞれに同じファームウェア**を書き込んでください。  

**デフォルトのファームウェアは右手側にUSB接続をするようになっています。(右手側がマスターの意味)**  
追記：左手側をマスターとした"Mooose_MasterLeft"というファームウェアも追加しました。  
追記：右手側マスター限定ですが、トラボスクロールの感度を調整した"mooose_Scroll2_Right"を追加しました。  

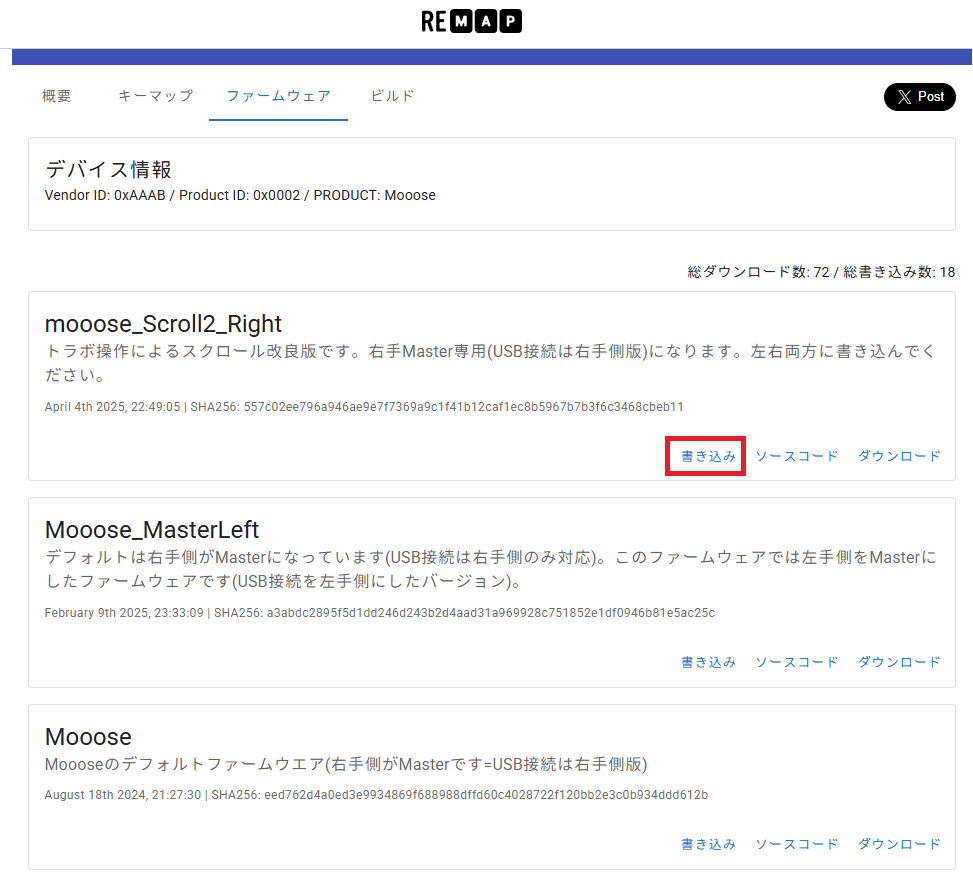
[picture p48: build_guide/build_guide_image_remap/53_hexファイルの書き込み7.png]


Bootloaderはcaterinaを選択し、FLASHをクリック。  
(日本語表記の場合は"書き込み"をクリック)
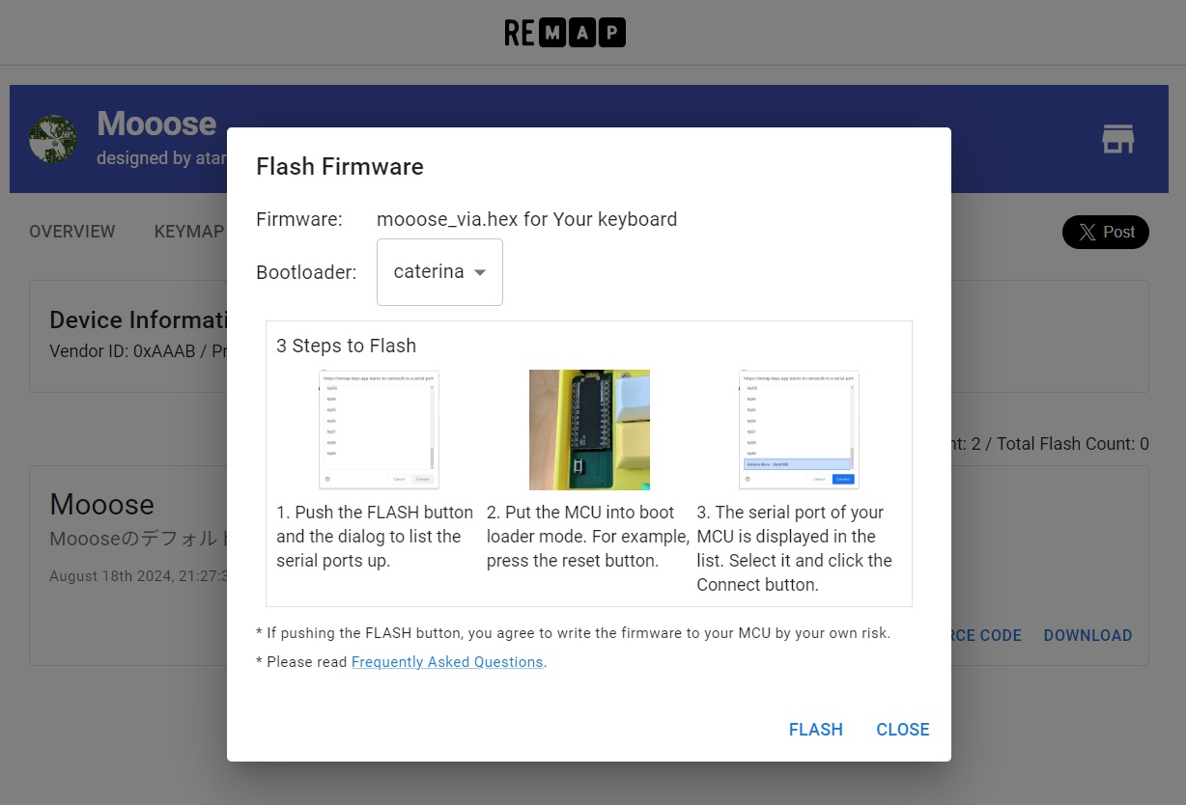
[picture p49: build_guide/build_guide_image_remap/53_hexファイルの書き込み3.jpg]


シリアルポートへの接続要求のポップアップが出ます。  
この状態で接続したキーボードのリセットスイッチ(promicroをリセット)を押してください。  
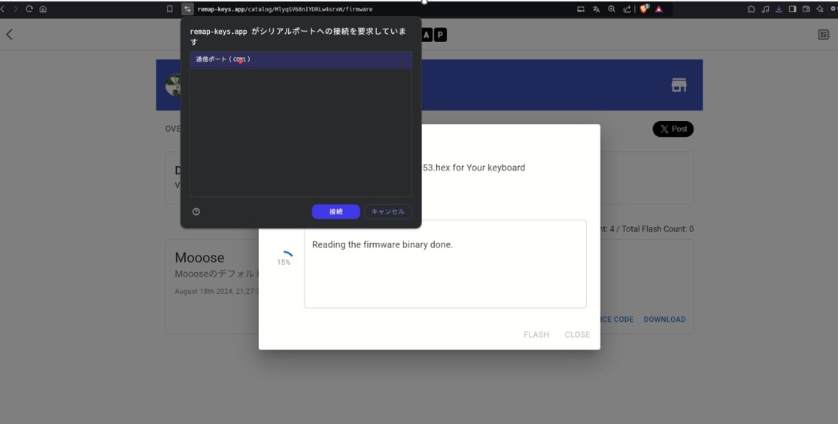
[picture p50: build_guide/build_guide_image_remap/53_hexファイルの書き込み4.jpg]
い

リセットスイッチを押すと"Arduino Leonardo"と表示されます。  
"Arduino Leonardo"を選択し、接続をクリックしてください。  
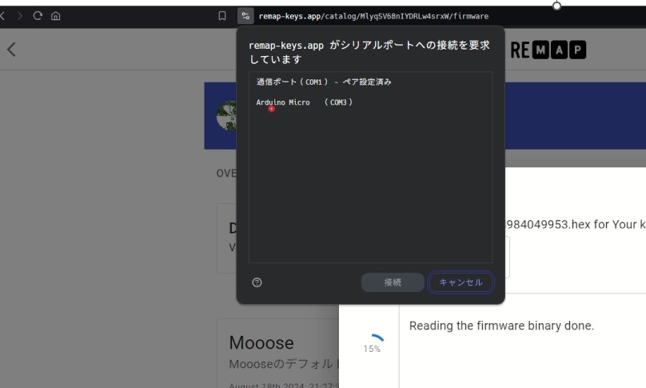
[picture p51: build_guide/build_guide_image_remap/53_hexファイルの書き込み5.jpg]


書き込みが進み"Writing the firmware finished successfuly"となれば完了です。  
パーセンテージも100%になれば完了です。  
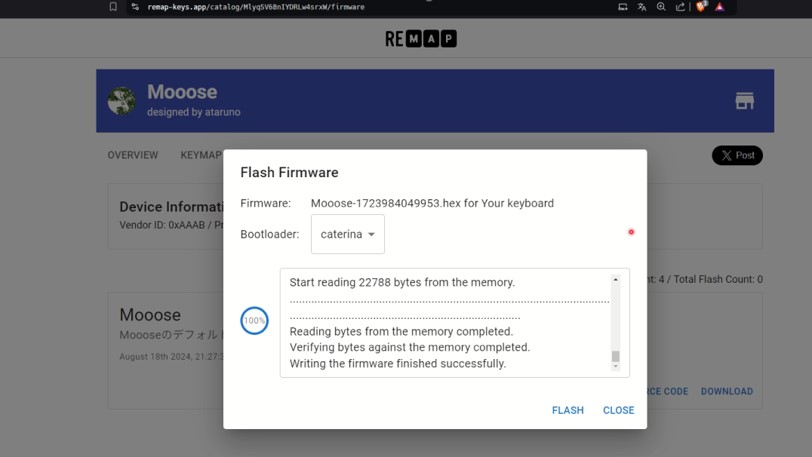
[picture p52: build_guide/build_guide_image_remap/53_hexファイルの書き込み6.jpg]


### 書き込み方法について別方法の紹介
上記の方法で問題なく書き込めていたら、"※別方法の紹介"と記載した部分は読み飛ばしても大丈夫です。  

#### hexファイルのダウンロード(※別方法の紹介)
Githubにあるhexファイルをダウンロードすることも可能です。  
[hexファイル(Remap)](https://remap-keys.app/catalog/MlyqSV68nIYDRLw4srxW/firmware)  

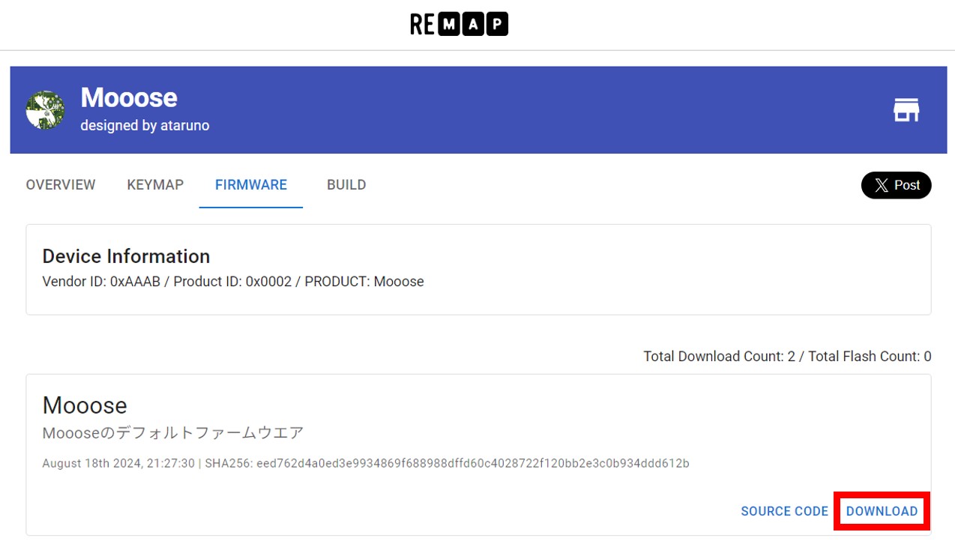
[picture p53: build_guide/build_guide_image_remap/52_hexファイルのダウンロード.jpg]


#### hexファイルの書き込み(※別方法の紹介)
ダウンロードしたファイルを用いたRemapでのプログラム書き込み方法です。  
その他の書き込み手段としては、Pro Micro Web UpdaterやQMK Toolboxでも可能です。  
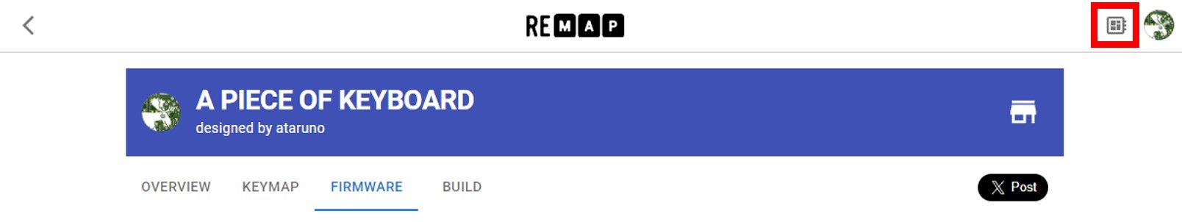
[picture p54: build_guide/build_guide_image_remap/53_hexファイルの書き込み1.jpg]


Remap右上のアイコンをクリックしてください。  

"Upload Firmware"のポップアップがでます。  
先ほどダウンロードしたhexファイルをドラッグ・アンド・ドロップしてください。  
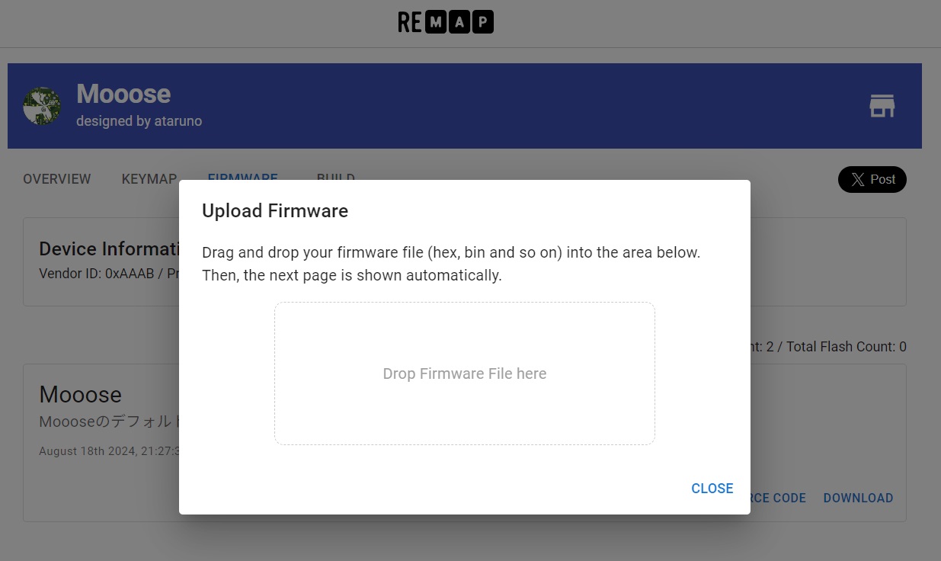
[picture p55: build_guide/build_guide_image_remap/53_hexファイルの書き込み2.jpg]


以降は先に説明した「Bootloaderはcaterinaを選択し、FLASHをクリック。」から続けてください。

## キーマップのカスタマイズ設定
キーマップの設定もRemapを活用できます。  

[Remap](https://remap-keys.app/)へ接続してください。  
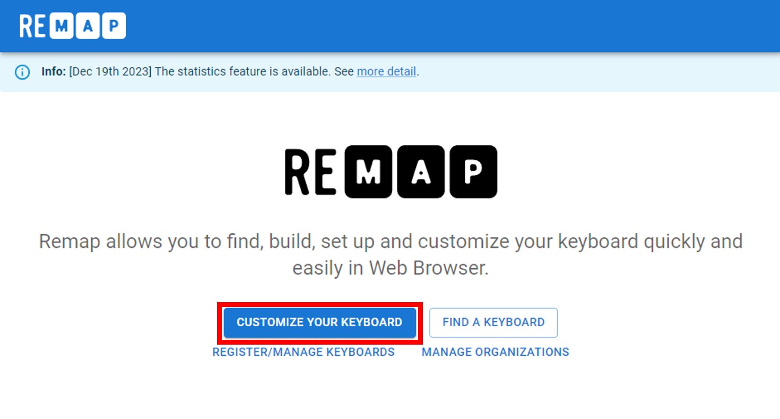
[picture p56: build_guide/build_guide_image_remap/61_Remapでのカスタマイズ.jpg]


"+KEYBOARD"をクリックしてください。  
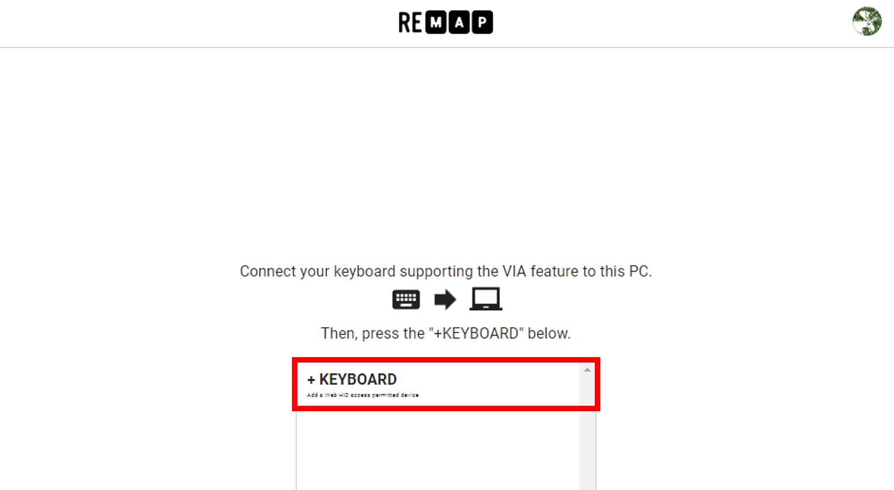
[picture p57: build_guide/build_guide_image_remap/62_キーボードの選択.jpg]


接続一覧から"Mooose"を選択し、"接続"をクリックしてください。  
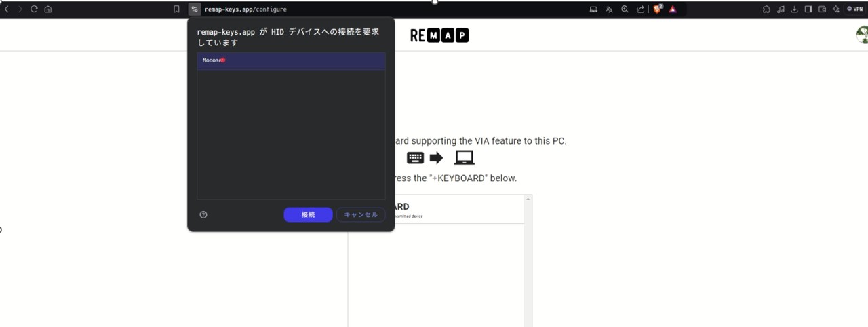
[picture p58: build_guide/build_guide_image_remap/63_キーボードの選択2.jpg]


### キーマップ設定と反映の仕方
キーマップの編集が終わったら、右上の"flash"をクリックしてください。  
下記の例では一か所"A"に変更しています。


右上が"SUCCESS"になればキーマップの書き換え完了です。  


### 補足：ロータリーエンコーダの設定
右回り、左回り、押込みの3つを設定できます。  
青色の矢印をクリックすると右回り、左回り、押込みが切替わります。  
これはレイヤーごとに設定できます。  


## Userキーについて
Moooseのデフォルトファームウェアには独自の設定キー/マクロキーが存在しています。  

### 前提
前提としてMicrosoft IMEで"変換"でIME-オン、"無変換"でIME-オフに設定しています。  
(全角入力/半角入力の切替を変換,無変換キーに割り当てるという意味です。)  


### Remap画面で内容のご紹介
Remap上では「User**」の表示で表されます。Remapの画面で解説をしていきます。  
レイヤー0  

レイヤー1  
※トラボ感度変更のマクロキーは廃止しました。
代わりに感度違いのhexファイルを用意したため、お好きな感度をお使いください。  
デフォルトファイルが一番感度が高く、cpiの値が小さくなるほど感度が低くなります。  
不思議なんですが、書き込み終わったら何かキーを打つとcpiが更新されます。  
[hexファイル置き場](https://github.com/ataruno/Mooose/tree/main/hex)  


レイヤー2  

レイヤー3  

レイヤー4  


※Remap上では設定したいキーをクリック"User"と入れると候補が出てきます。  


### Userキー一覧
#### レイヤー＆トラボ操作系
User1:長押しでレイヤー1になり、トラボはスクロール。(タップは“変換”)  
User2:長押しでレイヤー2になり、トラボは動きが小。0.4倍の移動量になります。(タップは“無変換”)  
User3:長押しでレイヤー3になり、トラボはスクロール。(タップは“Esc”)  
User4:長押しでレイヤー4になり、トラボは動きが小。0.4倍の移動量になります。(タップは“Tab”)  
#### マクロ入力系
User5:マクロです。無変換→’→’ ※半角入力になり、''が打たれます。プログラム書くとき楽。  
User6:マクロです。無変換→(→)   ※半角入力になり、()が打たれます。括弧打つのが楽。  
User7:マクロです。無変換→#      ※半角入力になり、#が打たれます。Markdown書くとき楽。  
User8:マクロです。無変換→<→ b→r →>  ※半角入力になり、<br>が打たれます。Markdown書くとき楽。  
User9:マクロです。無変換→*      ※半角入力になり、*が打たれます。Markdown書くとき楽。  
#### (実験)トラボ感度や角度
※cpi設定使いづらかったため消しました。
代わりに感度違いのhexファイルを用意したため、お好きな感度をお使いください。  
デフォルトファイルが一番感度が高く、cpiの値が小さくなるほど感度が低くなります。  
不思議なんですが、書き込み終わったら何かキーを打つとcpiが更新されます。  
[hexファイル置き場](https://github.com/ataruno/Mooose/tree/main/hex)  
~~User10:トラボ感度が下がる(CPIが増える)。※USB接続が外れるとデフォルト値へ戻る~~  
~~User11:トラボ感度が上がる(CPIが減る)。※USB接続が外れるとデフォルト値へ戻る~~  
~~User12:トラボ感度のリセット。(デフォルト値へ戻る)~~  
User13:トラボ角度が右に増加。※USB接続が外れるとデフォルト値へ戻る  
User14:トラボ角度が左に増加。※USB接続が外れるとデフォルト値へ戻る  
User15:トラボ角度のリセット。(デフォルト値へ戻る)  

```
※変数が揮発領域にあるのでUSB接続が外れるとデフォルト値に戻ってしまう…。  
  不揮発領域に保管できればUSB接続が外れても設定を引き継がれられると思うんだが。  
  プログラムをどう書けばよいかあまりわかっていないので実験的に追加しています。  
```

### ソースコードの該当箇所
プログラム的には以下のようにkeymap.cのswitch (keycode)、caseで定義しています。  
case文の頭から順に、RemapではUser0,User1…という表示になるようです。  
https://github.com/ataruno/Mooose/blob/main/qmk_keyboard_code/keymaps/via/keymap.c  


## 補足:build_guideの参考情報
* 不備情報  
* 改良した内容  
などを載せています。  

## 補足:Moooseのケース設計をしてみたい方へ
基板の3Dデータの一部を公開しています。  
https://github.com/ataruno/Mooose/blob/main/forCaseDesign/forCaseDesign.md

## 補足:あれ？動かないな？ってときの確認表
動かないぞ？となった際に確認すべき点をまとめてみました。
随時更新します。困った際は一度のぞいてみてください。
https://github.com/ataruno/Mooose/blob/main/build_guide/build_guide_QA.md

## おわりに
わからない点、不備などあればまずはBoothのメッセージ機能でご連絡ください。  
Xのリプライ/DMなどでも構いません。  
キーボード頒布が初めてな点、家庭用の3Dプリンターでの製造であること、個人開発品である点をご了承ください。  
よき自作キーボードライフを！

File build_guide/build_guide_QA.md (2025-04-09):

# あれ？動かないな？ってときの確認表

## 動作しない
* ファームウェアは正しく書き込めましたか？
  * 左右のプロマイクロには同じファームウェアを書き込んでください。
* プロマイクロをコンスルーで差し込むとき、奥まで差し込めていますか？
  * 接触が甘いと動作が不安定になります。
* プロマイクロをコンスルーで差し込むとき、位置は正しいですか？
  * 基板にはBAT+,BAT-の穴もありますが、通常つかいません。
* プロマイクロのはんだ付けは不足していないですか？
  * はんだが富士山型になるようはんだ付けしてください。
  * はんだが不足していると動作が不安定になる場合があります。

## キー入力ができない
* ダイオードの向きは正しいですか？
  * 間違えるあるあるです。大丈夫、はんだごてで熱を加えてダイオードを外しましょう。
  * ダイオードを外すときは基板のパッドをはがしてしまわぬよう気を付けてください。
  * ※ビルドガイドに写真あり。

## トラックボールが動かない
* トラックボールで使用するLEDはレンズの中心にきていますか？
  * 位置がずれていると動作が安定しない場合があります。
  * 手でくいっと持ち上げたり調整してください。
  * ※ビルドガイドに写真あり。

## やばい、基板のパッドが剥がれた…。
* Boothのメッセージ機能で連絡ください。
  * XのDMを一時的にでも開放しますので、写真など共有いただき状況教えてください。
  * もし、ワイヤーを空中配線などしてなんとか復旧可能そうならば「こことここを繋げるんだ！」とかアドバイスできるかもしれません。

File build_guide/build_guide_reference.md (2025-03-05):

# 参考情報

## ※不備情報
### 2024/11/1：初期ロット(1つ)ご購入のお客様へ  
状態：解決済み  
不備：部品"エンコーダ部分カバー"が左右反転状態で印刷されていた。  
対応：正しいパーツを再度郵送。  

## キット内容の更新

### 25/3/4以降
* promicro Type-Cでも干渉しないようケースを改良しました。
### 25/2月以降
* 右手側のロータリーエンコーダのノブもキット内容に含めました。

## ミドルプレートの改良
過去Verは上。新規Verは下。  
より安定するように形状が変わっています。特に親指まわり  



## 接着剤
あくまで一つの参考ですが、レザーとプラスチックの接着剤などが良いかと思います。  
[コニシ ボンドGクリヤー](https://www.amazon.co.jp/TRUSCO-%E3%83%9C%E3%83%B3%E3%83%89G%E3%82%AF%E3%83%AA%E3%83%A4%E3%83%BC-%E3%83%96%E3%83%AA%E3%82%B9%E3%82%BF%E3%83%BC%E3%83%91%E3%83%83%E3%8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)

私(ataruno)は以下を使っています。  
[セメダイン SUPER XG](https://www.amazon.co.jp/%E3%82%BB%E3%83%A1%E3%83%80%E3%82%A4%E3%83%B3-Cemedine-%E6%8E%A5%E7%9D%80%E5%89%A4%E3%82%B9%E3%83%BC%E3%83%91%E3%83%BCX%E3%82%B4%E3%83%BC%E3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)

レザークラフトのゴムのりでもよいかと思います。

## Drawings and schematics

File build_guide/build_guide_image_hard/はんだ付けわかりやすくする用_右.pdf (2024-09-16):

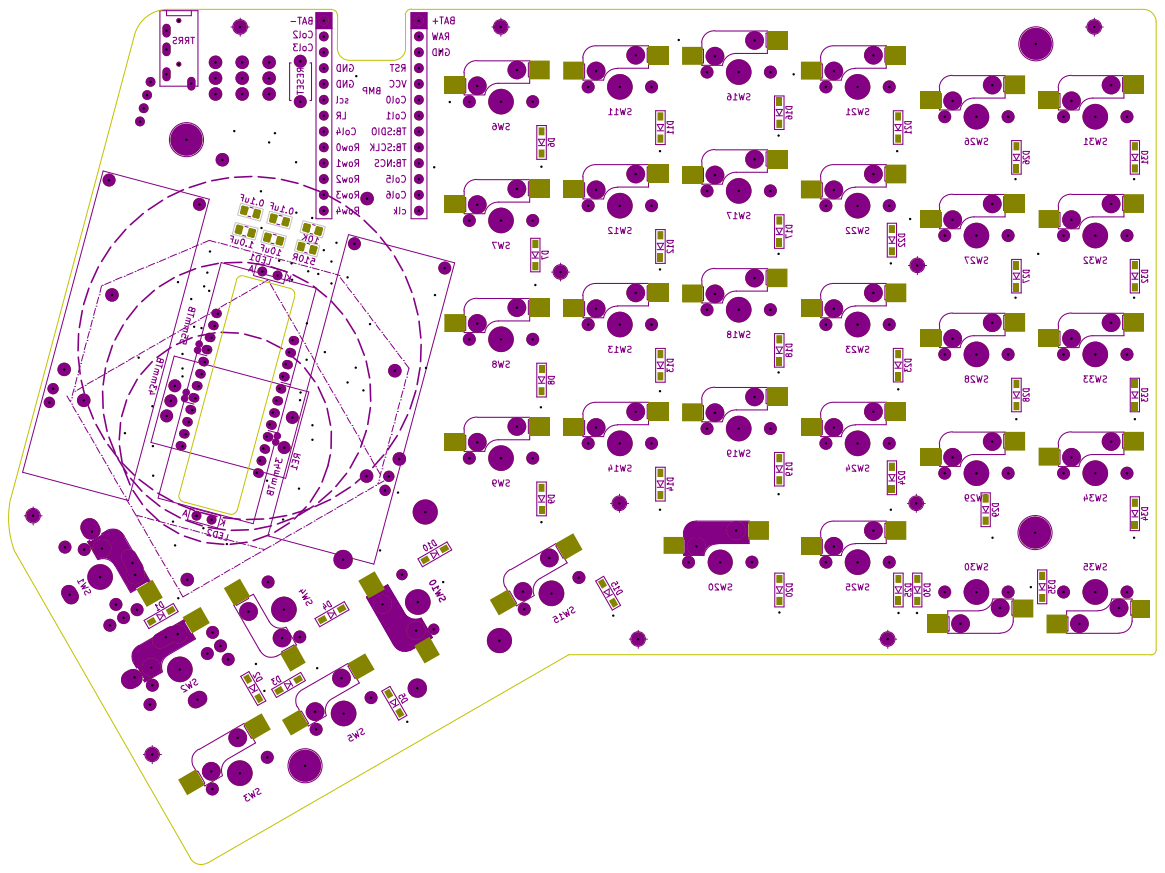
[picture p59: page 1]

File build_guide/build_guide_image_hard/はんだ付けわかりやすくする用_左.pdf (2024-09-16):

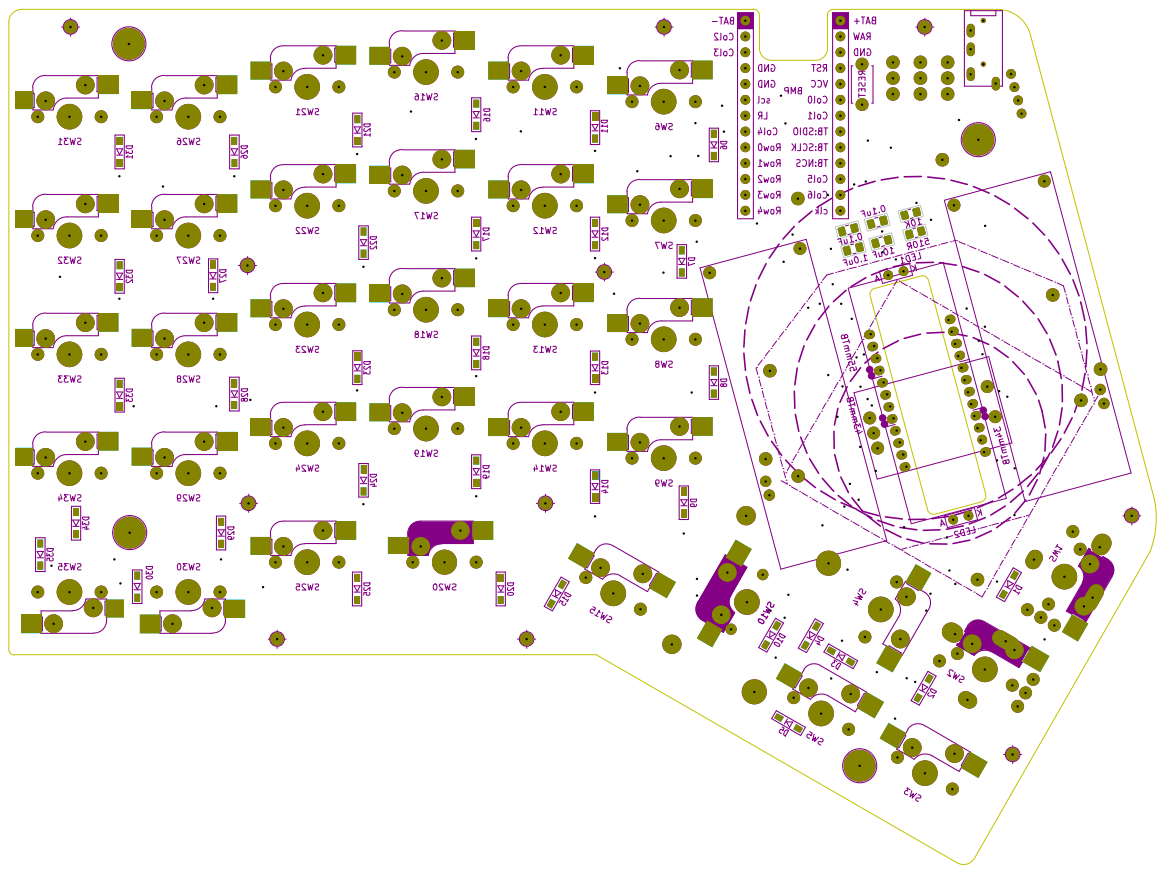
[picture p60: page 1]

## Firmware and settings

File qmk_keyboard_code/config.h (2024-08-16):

// Copyright 2023 ataruno (@ataruno)
// SPDX-License-Identifier: GPL-2.0-or-later

#pragma once

// #include "config_common.h"

/* key matrix size */
#define MATRIX_ROWS 10
#define MATRIX_COLS 7

// wiring of each half
// #define DIRECT_PINS { { B6, B3, B2, NO_PIN} }
// #define UNUSED_PINS { F4, F5, D4, C6, D7, E6, B4, B5}
// #define MATRIX_ROW_PINS { C6, D7, E6 ,B4 ,B5}
// #define MATRIX_COL_PINS { F4, F5, D3, D2, D4, B3, B2 }

/* COL2ROW, ROW2COL */
// #define DIODE_DIRECTION COL2ROW

/* Set 0 if debouncing isn't needed */
#define DEBOUNCE 5

/* Mechanical locking support. Use KC_LCAP, KC_LNUM or KC_LSCR instead in keymap */
#undef LOCKING_SUPPORT_ENABLE
/* Locking resynchronize hack */
#undef LOCKING_RESYNC_ENABLE

/* Limit the maximum layer number to 8 */
// #define LAYER_STATE_8BIT

/* Rotary encoder */
#define ENCODERS_PAD_A { D1 }
#define ENCODERS_PAD_B { B6 }
#define ENCODER_RESOLUTION 4

// #define TAPPING_FORCE_HOLD
#define TAPPING_TERM 200

#define MASTER_RIGHT
#define SOFT_SERIAL_PIN D0

#define SPLIT_POINTING_ENABLE
// #define POINTING_DEVICE_COMBINED
#define POINTING_DEVICE_RIGHT
// #define POINTING_DEVICE_LEFT
#define DISABLE_SYNC_TIMER
// #define COMBO_NO_TIMER
// #define SPLIT_MAX_CONNECTION_ERRORS 0
// #define SPLIT_TRANSPORT_MIRROR

#define ADNS5050_SDIO_PIN         F6
#define ADNS5050_SCLK_PIN         F7
#define ADNS5050_CS_PIN           B1
// #define POINTING_DEVICE_ROTATION_RIGHT_180
#define POINTING_DEVICE_DEBUG

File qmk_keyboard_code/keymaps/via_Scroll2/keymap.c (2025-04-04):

// Copyright 2023 QMK
// SPDX-License-Identifier: GPL-2.0-or-later

#include QMK_KEYBOARD_H

#define _BASE 0
#define _LOWER 1
#define _RAISE 2
#define _AHK 3
#define _NUM 4

enum custom_keycodes {
    BASE = SAFE_RANGE,
    LOWER,
    RAISE,
    AHK,
    NUM,
    MY_Squo,
    MY_Parentheses,
    MY_Shrp,
    MY_Br,
    MY_Ast,
    MY_CPIp,
    MY_CPIm,
    MY_CPId,
    MY_Anglep,
    MY_Anglem,
    MY_Angled
};

const uint16_t PROGMEM keymaps[][MATRIX_ROWS][MATRIX_COLS] = {
    [_BASE] = LAYOUT(
      KC_ESC,KC_1,KC_2,KC_3,KC_4,KC_5,KC_MUTE,
      KC_TAB,KC_Q,KC_W,KC_E,KC_R,KC_T,KC_ENT,
      KC_LALT,KC_A,KC_S,KC_D,KC_F,KC_G,LCTL(KC_SLSH),
      KC_LSFT,KC_Z,KC_X,KC_C,KC_V,KC_B,KC_DEL,
      KC_LCTL,KC_LGUI,KC_LALT,NUM,KC_BSPC,KC_SPC,LOWER,
      KC_MS_BTN3,      KC_6,   KC_7,   KC_8,   KC_9,   KC_0,    KC_PSCR,
      KC_MS_BTN1,      KC_Y,   KC_U,   KC_I,   KC_O,   KC_P,    KC_INT3,
      KC_MS_BTN3,      KC_H,   KC_J,   KC_K,   KC_L,   KC_SCLN, KC_QUOT,
      KC_MS_BTN2,      KC_N,   KC_M,   KC_COMM,KC_DOT, KC_SLSH, KC_RSFT,
      RAISE,           KC_ENT, KC_MINS,AHK,    KC_RBRC,KC_NUHS, KC_LBRC
    ),
    [_LOWER] = LAYOUT(
      KC_ESC,KC_F2,KC_F2,KC_F3,KC_F4,KC_F5,KC_F11,
      KC_TAB,LCTL(KC_T),KC_MS_BTN1,LGUI(KC_UP),LSFT(KC_F10),LALT(LSFT(KC_TAB)),0x0068,
      KC_LALT,LCTL(KC_W),LGUI(KC_LEFT),LALT(LCTL(KC_TAB)),LGUI(KC_RGHT),LALT(KC_TAB),0x0069,
      KC_LSFT,LGUI(KC_S),LALT(KC_F4),LGUI(KC_DOWN),LGUI(KC_T),LGUI(KC_TAB),KC_DEL,
      KC_LCTL,KC_LGUI,KC_LALT,_______,KC_BSPC,KC_SPC,_______,
      KC_EQL,            KC_F6 ,     KC_F7 ,     KC_F8 ,     KC_F9 ,     KC_F10 ,    KC_PAUS ,
      LCTL(LSFT(KC_TAB)),KC_PAST ,   KC_P7 ,     KC_P8 ,     KC_P9 ,     KC_PMNS ,   KC_INT3 ,
      LCTL(KC_TAB),      KC_PSLS ,   KC_P4 ,     KC_P5 ,     KC_P6 ,     KC_PPLS ,   MY_CPId,
      KC_MS_BTN3 ,         KC_QUOT ,   KC_P1 ,     KC_P2 ,     KC_P3 ,     KC_EQL ,    KC_RSFT,
      _______,           KC_ENT ,    KC_MINS ,   KC_P0 ,     KC_PDOT ,   MY_CPIm ,   MY_CPIp
      ),
    [_RAISE] = LAYOUT(
      KC_ESC,KC_F2,KC_F2,KC_F3,KC_F4,KC_F5,KC_F11,
      KC_TAB,KC_Q,KC_W,KC_E,KC_R,KC_T,0x0068,
      KC_LALT,KC_A,KC_S,KC_D,KC_F,KC_G,0x0069,
      KC_LSFT,KC_Z,KC_X,KC_C,KC_V,KC_B,KC_DEL,
      KC_LCTL,KC_LGUI,KC_LALT,NUM,KC_BSPC,KC_SPC,_______,
      KC_F12 ,        KC_F6 ,     KC_F7 ,     KC_F8 ,     KC_F9 ,     KC_F10 ,     KC_PAUS ,
      KC_WWW_FORWARD, KC_MS_BTN1 ,  KC_HOME ,   KC_UP ,     KC_END ,    LSFT(KC_F10),KC_ESC ,
      KC_WWW_BACK,    KC_HOME ,   KC_LEFT ,   KC_DOWN ,   KC_RGHT ,   KC_END ,     MY_Angled ,
      KC_MS_BTN3 ,      KC_PGDN ,   MY_Shrp    ,MY_Parentheses , MY_Squo, KC_PGUP,   KC_RSFT ,
      _______,        MY_Br ,    KC_INT1 ,   AHK,        KC_WH_R ,    MY_Anglem ,   MY_Anglep
    ),
    [_AHK] = LAYOUT(
      KC_ESC,KC_F2,KC_F2,KC_F3,KC_F4,KC_F5,KC_F11,
      KC_TAB,KC_F15,KC_F16,KC_F17,KC_F18,KC_F19,KC_MS_BTN1,
      KC_LALT,LCTL(KC_F15),LCTL(KC_F16),LCTL(KC_F17),LCTL(KC_F18),LCTL(KC_F19),KC_MS_BTN2,
      KC_LSFT,LSFT(KC_F15),LSFT(KC_F16),LSFT(KC_F17),LSFT(KC_F18),LSFT(KC_F19),KC_DEL,
      KC_LCTL,KC_LGUI,KC_LALT,NUM,KC_BSPC,KC_SPC,_______,
      KC_F12 ,        KC_F6 ,       KC_F7,       KC_F8,       KC_F9,             KC_F10,  KC_PAUS,
      KC_MS_BTN1,      KC_F20,       KC_F21,      KC_F22,      KC_F23,            KC_F24,  KC_ESC,
      KC_MS_BTN3,  LCTL(KC_F20), LCTL(KC_F21), LCTL(KC_F22),LCTL(KC_F23),    LCTL(KC_F24),  KC_ESC,
      KC_MS_BTN2,  LSFT(KC_F20), LSFT(KC_F21), LSFT(KC_F22),LSFT(KC_F23),    LSFT(KC_F24),  KC_RSFT,
      _______,       KC_ENT ,      KC_INT1,  _______,         KC_WH_R,           KC_NO,  KC_LBRC
    ),
    [_NUM] = LAYOUT(
      KC_ESC,KC_F1,KC_F2,KC_F3,KC_F4,KC_F5,KC_F11,
      KC_TAB,LSFT(KC_1),LSFT(KC_2),LSFT(KC_3),LSFT(KC_4),LSFT(KC_5),KC_ENT,
      KC_LALT,LALT(KC_1),LALT(KC_2),LALT(KC_3),LALT(KC_4),LALT(KC_5),KC_F11,
      KC_LSFT,KC_F1,KC_F2,KC_F3,KC_F4,KC_F5,KC_DEL,
      KC_LCTL,KC_LGUI,KC_LALT,_______,KC_BSPC,KC_SPC,LOWER,
      KC_F12 ,    KC_F6 ,          KC_F7,     KC_F8,     KC_F9,       KC_F10,       KC_PSCR,
      KC_EQL,        LSFT(KC_6), LSFT(KC_7),LSFT(KC_8),LSFT(KC_9), LSFT(KC_0),         KC_ESC,
      KC_F12,         LALT(KC_6), LALT(KC_7), LALT(KC_8), LALT(KC_9), LALT(KC_0), KC_QUOT,
      KC_MS_BTN3,       KC_F6 ,          KC_F7,     KC_F8,     KC_F9,       KC_F10,       KC_RSFT,
      RAISE,          KC_ENT,          KC_MINS,   AHK,       KC_RBRC,     KC_NUHS,      KC_LBRC
    )
};


#if defined(ENCODER_MAP_ENABLE)
const uint16_t PROGMEM encoder_map[][NUM_ENCODERS][NUM_DIRECTIONS] = {
    [_BASE] =   { ENCODER_CCW_CW(KC_MS_WH_UP, KC_MS_WH_DOWN),ENCODER_CCW_CW(KC_MS_WH_DOWN,KC_MS_WH_UP)},
    [_LOWER] =  { ENCODER_CCW_CW(KC_MS_WH_UP, KC_MS_WH_DOWN),ENCODER_CCW_CW(KC_MS_WH_DOWN,KC_MS_WH_UP)},
    [_RAISE] =  { ENCODER_CCW_CW(KC_MS_WH_UP, KC_MS_WH_DOWN),ENCODER_CCW_CW(KC_MS_WH_DOWN,KC_MS_WH_UP)},
    [_AHK] =    { ENCODER_CCW_CW(KC_VOLU,KC_VOLD), ENCODER_CCW_CW(KC_VOLD, KC_VOLU)},
    [_NUM] =    { ENCODER_CCW_CW(KC_VOLU,KC_VOLD), ENCODER_CCW_CW(KC_VOLD, KC_VOLU)}
};
#endif

bool encoder_update_user(uint8_t index, bool clockwise) {
    if (index == 0) { /* First encoder */
        if (clockwise) {
            tap_code(KC_MS_WH_DOWN);
        } else {
            tap_code(KC_MS_WH_UP);
        }
    } else if (index == 1) {
        if (clockwise) {
            tap_code(KC_MS_WH_DOWN);
        } else {
            tap_code(KC_MS_WH_UP);
        }
    }
    return false;
}

static bool lower_pressed = false;
static uint16_t lower_pressed_time = 0;
static bool raise_pressed = false;
static uint16_t raise_pressed_time = 0;
static bool last_low_cpi_mode;
bool low_cpi_mode;
bool isScrollMode;
bool isPointM_low;
uint16_t _cpi;
uint16_t temp_cpi;
double angle_degrees = 0;
double cos_theta = 1;
double sin_theta = 1;
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

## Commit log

2024-09-16 ビルドガイド更新
2024-09-19 画像追加
2024-10-16 QRコード画像の追加
2024-10-16 Readme更新
2024-12-21 不備情報を解決済みへ更新
2024-12-27 Userキー設定の画像追加
2024-12-27 説明図を追加
2024-12-27 説明画像追加
2024-12-27 独自キーの内容説明追加
2024-12-28 ロータリーエンコーダの挙動の図を追加
2024-12-28 ロータリーエンコーダの挙動の説明を追加
2025-02-09 左手MASTERのhexファイル追加
2025-02-09 左手MASTERのファームウェア追加を追記
2025-02-17 Moooseのケース設計をしてみたい方へ
    [Mooose右_シルク表面.stl, Mooose右_シルク裏面.stl, Mooose右_基板形状.stl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]
2025-04-12 ロータリーエンコーダのRemap設定を追記
2025-04-27 ロータリーエンコーダの高さについて
2025-08-24 hexファイルを追加
2025-10-16 トラボ感度違いのhexファイルを追加
2025-10-16 説明書き更新
